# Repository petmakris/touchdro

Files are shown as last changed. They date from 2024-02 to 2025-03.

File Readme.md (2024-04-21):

# Parts

* ESP32 DEVKIT V1
    - https://www.aliexpress.us/item/2255800094862861.html

* Micro USB Connector Breakout 

  - https://www.aliexpress.com/item/1005006088838882.html

* ±5% 100V 100nF -40℃~+110℃ Metallized Polyester Plugin,P=5mm

    - [C3034534](https://www.lcsc.com/product-detail/Film-Capacitors_KNSCHA-MEB104J100V82CB0018_C3034534.html)

* 47uF 50V ±20% 180mA@100kHz Plugin,D6.3xL12mm 

    - [C2831773](https://www.lcsc.com/product-detail/Aluminum-Electrolytic-Capacitors-Leaded_KNSCHA-03EC0571_C2831773.html)

* Metal Film Resistors 4.7kΩ 250mW ±100ppm/℃ ±1%
 
    - [C119339](https://www.lcsc.com/product-detail/Through-Hole-Resistors_CCO-Chian-Chia-Elec-MF1-4W-4-7K-1-T_C119339.html)

* Metal Film Resistors 47kΩ 250mW ±50ppm/℃ ±1%

    - [C410613](https://www.lcsc.com/product-detail/Through-Hole-Resistors_TyoHM-RN-1-4W-47K-F-T-B-A1_C410613.html)

* SN74HC14N Schmitt Trigger 6 21ns@6V,50pF 2uA 2V~6V DIP-14 Inverters ROHS

    - [C2907](https://www.lcsc.com/product-detail/Inverters_Texas-Instruments-SN74HC14N_C2907.html)

# Micro USB Breakout

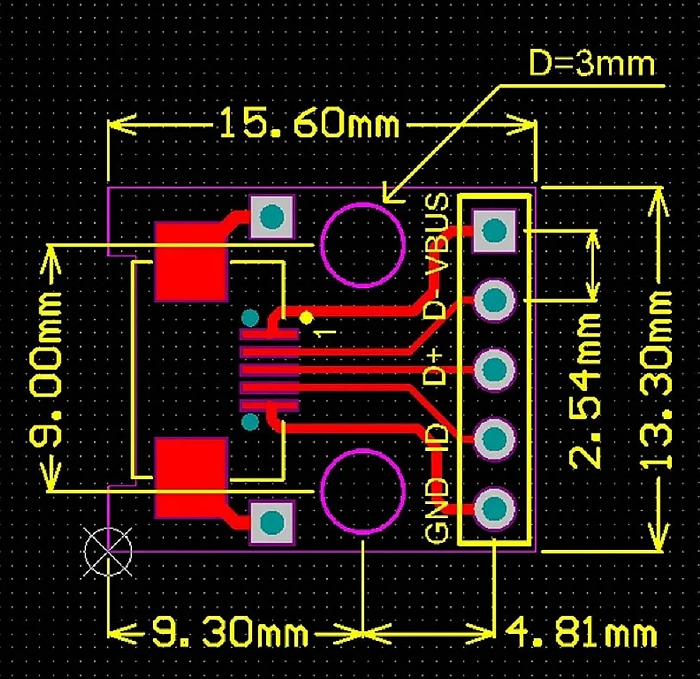
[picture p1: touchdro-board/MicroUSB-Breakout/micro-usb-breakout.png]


# ESP32 DevKit V1

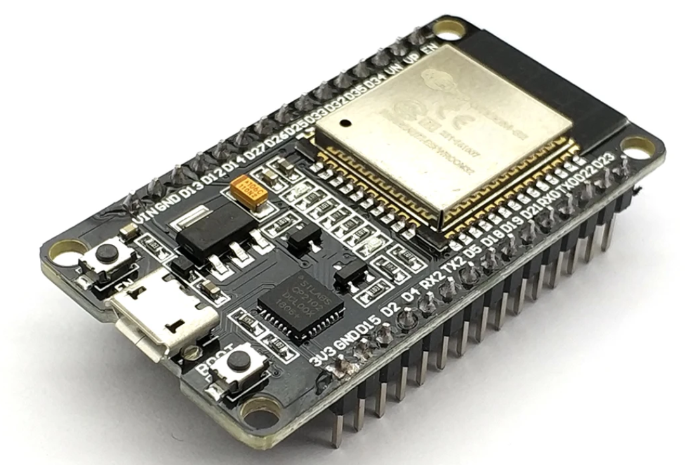
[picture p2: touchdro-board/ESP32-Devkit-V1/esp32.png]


# Firmware

```bash
esptool.py --chip esp32 --port COM5 --baud 460800 --before default_reset --after hard_reset write_flash --flash_mode dio --flash_size detect --flash_freq 40m 0x1000 bootloader.bin 0x8000 partition-table.bin 0x10000 touchdro-diy-universal-1.6.bin
```

It seems that for the esp32 to broadcast you need to keep the boot 
button pressed

# References

- https://www.touchdro.com/resources/adapters/diy/esp32-diy-dro.html
- https://gitlab.com/VictorLamoine/kicad

https://www.touchdro.com/resources/adapters/diy/esp32-diy-dro.html

# Ordering from JLCPCB

## Step 1

from within `PCB`: 

- Export Gerber files
- Export Drill Files

- Export Placement file
  - Separate files for front/back
  - Keep only top file
  - Remove components not to be mounted

## Step 2 

from within `Schematic`:

Create BOM compatible with JLCPCB the custom plugin from within our `kicad-libs` projecs:

KicadBOM

This plugin will include only the components with a `JLCPCB` attributes

# Production files

kicad_pos_to_cpl.py POSITION.POSITION-JLCPCB.csv overrides.json [overrides.json]

## Tune placement file

Example `overrides.json`:

```json
{
    "D3": 180,
    "Q1": 180,

    "U6": -90,
    "U8": -90
}
```

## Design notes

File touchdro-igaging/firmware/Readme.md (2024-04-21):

Boards:

# Glass and magnetic scales

Use STM32F103C8T6 
    - Support for TTL single ended or rs422 scales
    - Auto detection of pinout using analog switch matrix

# Capacitive scales

- iGaging DigiMag Remote DRO
- iGaging EZ-View DRO Plus
- AccuRemote DRO
- Shars Digital Machine Scale
- iGaging Absolute DRO Plus
...

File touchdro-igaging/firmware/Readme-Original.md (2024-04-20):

NOTE: This program supports pulse sensor to measure rpm and switch type touch probe.  
For quadrature encoder scales use LS7366R-based shield.

If at least one quadrature scale is used do not conect other devices to SPI dedicated pins
as LS7366R uses SPI for communication

Configuration parameters:

- `SCALE_<n>_ENABLED`

Defines if DRO functionality on axis <n> should be supported.
If supported DRO scale should be connected to I/O pin defined in constant "<n>DataPin" and
DRO data is sent to serial port with corresponding axis prefix (X, Y, Z or W)
Clock pin is common for all iGaging scales should be connected to I/O pin defined in constant "clockPin"
Possible values:
    0 = DRO functionality on axis <n> is not supported
    1 = DRO functionality on axis <n> is supported
Default value = 1

- `SCALE_<n>_TYPE`

Defines the type of scale used on axis <n>.
Two types of scales are supported: iGaging/AccuRemote Digital Scales and  quadrature encoder scales (common glass or magnetic)
Note: If at least on scale is type 1 do not connect any other devices to SPI pins as it will interfere with communication with LS7366R.
Possible values:
    0 = iGaging/AccuRemote Digital Scales with 21bit protocol
    1 = Quadrature Encoder scales through LS7366R-type shield (32-bit quadrature counter with serial interface).
Default value = 0

- `SCALE_CLK_PIN`

Defines the I/O pin where clock signal for all iGaging DRO scales is connected.  Used only if at least one scale is type 0.
Possible values:
    integer number between 2 and 13
Default value = 2

- `SCALE_<n>_PIN`

Defines the I/O pin where DRO data signal for selected scale is connected
Note: For quadrature scale this pin is connected to SPI SS pin in corresponding LS7366R.
Possible values:
    integer number between 2 and 13
Default values = 3, 4, 5, 6 (for corresponding axis X, Y, Z and W)

- `SCALE_<n>_AVERAGE_ENABLED`

Defines if DRO reading should be averaged using weighted average calculation with automating smoothing factor.
If average is enabled the reading is much more stable without "jumping" and "flickering" when the scale "can't decide" on the value.
Note: This value is not used when corresponding SCALE_<n>_ENABLED is 0
Possible values:
    0 = exact measured from the scale is sent
    1 = scale reading averaged using weighted average calculation with automatic smoothing factor
Default value = 1

- `AXIS_AVERAGE_COUNT`

Defines the number of last DRO readings that will be used to calculate weighted average for DRO.
For machines with power feed on any axis change this value to lower number i.e. 8 or 16.
Possible values:
    integer number between 4 and 32
Recommended values:
    16 for machines with power feed
    32 for all manual machines
Default value = 24

- `TACH_ENABLED`

Defines if tach sensor functionality should be supported.
If supported tach sensor should be connected to I/O pin defined in constant INPUT_TACH_PIN and
rpm value is sent to serial port with axis prefix "T"
Possible values:
    0 = tach sensor functionality is not supported
    1 = tach sensor functionality is supported
Default value = 1

- `INPUT_TACH_PIN`

Defines the I/O pin where tach sensor signal is connected
Possible values:
    integer number between 2 and 13
Default value = 7

- `TACH_PRESCALE`

Defines how many tach pulses per one revolution the sensor sends.
For example if tach sensor uses two magnets on the shaft the sensor will generate two pulses per revolution.
This can be used to get better resolution and faster response time for very low rpm
Note: This value is not used when TACH_RAW_DATA_FORMAT is enabled
Possible values:
    any integer number greater than 0
Default value = 1

- `TACH_AVERAGE_COUNT`
  
Defines the number of last tach readings that will be used to calculate average tach rpm.
If you want to send measured rpm instead of average rpm set this value to 1.
Note: This value is not used when TACH_RAW_DATA_FORMAT is enabled.
        It is recommended to set this value 2 times or more of TACH_PRESCALE value.
        For example: if TACH_PRESCALE = 4, set TACH_AVERAGE_COUNT = 8
Possible values:
    1 = exact measured tach reading is sent
    any integer number greater than 1 - average tach reading is sent
Default value = 6

- `TACH_ROUND`
    Defines how tach reading should be rounded. If rounding is enabled the reading can be rounded either by 1% of current rpm or to the fixed "round" number with predefined RPM thresholds ("smart rounding"). For example with 1% rounding if measured rpm is between 980rpm and  1020 rpm the display will show numbers rounded to 9 and 10 (i.e. 981, 990, 999, 1000, 1010, 1020 etc.). With "smart rounding" the measured rpm is rounded to the nearest 1, 2, 5, 10, 20, 50 and 100 depends on measured RPM (change at predefined thresholds). For example with "smart rounding" all measured rpm is between 500pm and  2000 rpm the display will show numbers rounded to the nearest 5 (i.e. 980, 985, 990, 995, 1000, 1005  etc.). Note: This value is not used when TACH_RAW_DATA_FORMAT is enabled Possible values: 0 = exact measured tach reading is sent 1 = tach reading is rounded to the nearest 1% of measured rpm (1% rounding) 2 = tach reading is rounded to the nearest "round" number with fixed thresholds ("smart rounding") Default value = 2

- `TACH_RAW_DATA_FORMAT`
    Defines the format of tach data sent to serial port.
    Note: when raw data format is used, then TACH_PRESCALE, TACH_AVERAGE_COUNT and TACH_ROUND are ignored
    Possible values:
        0 = tach data is sent in single value format: T<rpm>;
        1 = tach data is sent in raw (two values) format: T<total_time>/<number_of_pulses>;
    Default value = 0

- `MIN_RPM_DELAY`
    Defines the delay (in milliseconds) in showing 0 when rotation stops.  If rpm is so low and time between tach pulse
    changes longer than this value, value zero rpm ("T0;") will be sent to the serial port.
    Note: this number will determine the slowest rpm that can be measured.  In order to measure smaller rpm I suggest
            to use a sensor with more than one "ticks per revolution" (for example hall sensor with two or more magnets).
            The number of "ticks per revolution" should be set in tachometer setting in Android app.
    Possible values:
        any integer number greater than 0
    Default value = 1200 (the minimum rpm measured will be 50 rpm)

- `OUTPUT_TACH_LED_ENABLED`
    Defines if the tach LED feedback is supported.
    If supported the tach feedback LED should be connected to I/O pin defined in constant OUTPUT_TACH_LED_PIN below
    Possible values:
        0 = tach LED feedback functionality is not supported
        1 = tach LED feedback functionality is supported
    Default value = 1

- `OUTPUT_TACH_LED_PIN`
    Defines the I/O pin where the tach LED feedback is connected.
    Tach LED feedback indicates the status of INPUT_TACH_PIN for debugging purposes
    Possible values:
        integer number between 2 and 13
    Default value = 9

- `PROBE_ENABLED`
    Defines if touch probe sensor functionality should be supported.
    If supported touch probe should be connected to I/O pin defined in constant INPUT_PROBE_PIN.
    Possible values:
        1 = touch probe functionality is supported
        0 = touch probe functionality is not supported
    Default value = 1

- `INPUT_PROBE_PIN`
    Defines the I/O pin where touch probe signal is connected
    Possible values:
        integer number between 2 and 13
    Default value = 8

- `PROBE_INVERT`
    Defines if the touch probe input pin signal needs to be inverted (enter the signal level when touch probe is not touching).
    Possible values:
        0 = touch probe input pin signal is LOW (logical Zero) when touch probe is in "normal open" status (not touching)
        1 = touch probe input pin signal is HIGH (logical One) when touch probe is in "normal open" status (not touching)
    Default value = 0

- `OUTPUT_PROBE_LED_ENABLED`
    Defines if the touch probe LED feedback is supported.
    If supported the touch probe feedback LED should be connected to I/O pin defined in constant INPUT_PROBE_PIN below
    Possible values:
        1 = touch probe LED feedback functionality is supported
        0 = touch probe LED feedback functionality is not supported
    Default value = 1

- `OUTPUT_PROBE_LED_PIN`
    Defines the I/O pin where the touch probe LED feedback is connected.
    Touch probe LED feedback indicates the status of INPUT_PROBE_PIN for debugging purposes
    Possible values:
        integer number between 2 and 13
    Default value = 10

- `UART_BAUD_RATE`
    Defines the serial port baud rate.  Make sure it matches the Bluetooth module's baud rate.
    Recommended value:
        1200, 2400, 4800, 9600, 19200, 38400, 57600, 115200
    Default value = 9600

- `UPDATE_FREQUENCY`
    Defines the Frequency in Hz (number of timer per second) the scales are read and the data is sent to the application.
    Possible values:
        any integer number between 1 and 64
    Default value = 24

- `TACH_UPDATE_FREQUENCY`
    Defines the max Frequency in Hz (number of timer per second) the tach output is sent to the application.
    Note: This value must be a divider of UPDATE_FREQUENCY that would result zero reminder.
            For example for UPDATE_FREQUENCY = 24 valid TACH_UPDATE_FREQUENCY are: 1, 2, 3, 4, 6, 8, 12 and 24
    Possible values:
        any integer number between 1 and UPDATE_FREQUENCY
    Default value = 4

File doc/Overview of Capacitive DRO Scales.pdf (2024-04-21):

Home (https://www.touchdro.com/) > Resources (https://www.touchdro.com/resources/) > Capacitive DRO Scales

# Overview of Capacitive DRO Scales

Capacitive linear scales have been popular with budget-conscious home machinists for the better part of three decades. The main appeal of capacitive scales is their low cost that gives the hobbyists access to a functional digital readout for a fraction of the cost of an off-the-shelf DRO. On top of that, these scales can be easily cut to the needed size making them preferable for smaller machines. As is the case with all DRO scales, capacitive scales have their pros and cons, (https://www.touchdro.com/resources/scales/capacitive/pros-and-cons.html) so it's important to have at least a cursory understanding of the most important DRO scale characteristics. (https://www.touchdro.com/resources/scales/dro-scale-parameters.html)

There is a large number of capacitive scale models on the market offered by several manufacturers. While they might look similar on the outside, there are many important internal differences between capacitive DRO scales, (https://www.touchdro.com/resources/scales/capacitive/important-differences.html) including data format, communication protocol, and power supply voltage. The good news is that TouchDRO can interface with the vast majority of Chinese linear scales on the market, but different scales have different adapter hardware and firmware requirements. To make sure that you select the compatible combination of scales, TouchDRO adapter and firmware, please refer to the list below.

# Supported Scales

TouchDRO relies on custom adapter firmware to interface with various models of capacitive scales. At the time of this writing, most mainstream linear scales and a number of other specialty scales are supported. Each scale family had different interfacing hardware requirements and decoding firmware. The list below contains details about supported capacitive scale families, their important characteristics, and TouchDRO adapter compatibility.

Home (https://www.touchdro.com/) | Store (https://store.touchdro.com/) | Downloads (https://www.touchdro.com/downloads.html) | Documentation (https://www.touchdro.com/resources/)

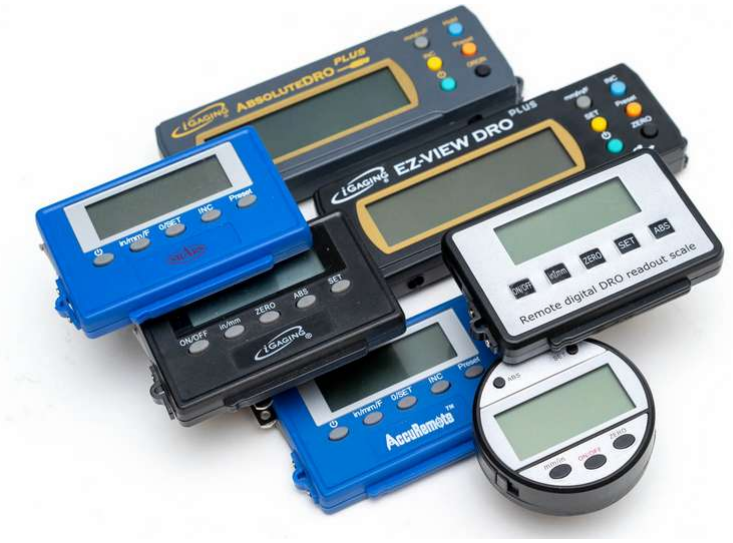
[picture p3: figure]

Please note that this list is not comprehensive. It's impossible to test and verify every scale model on the market; so, even if your scales are not listed, it might still work just fine with TouchDRO. You will need to do some research and testing on your own though.

## iGaging DigiMag Remote DRO

iGaging DigiMag was the first capacitive scale model with a display that can be mounted remotely. They use an extruded aluminum frame in conjunction with an injection-molded plastic transducer housing. The display is connected to the reading head using a USB cable that is glued to the transducer board and has a male plug on the display end. The scales are powered via two 3V cells connected in parallel.
Read More (https://www.touchdro.com/resources/scales/capacitive/igaging-21-bit.html)

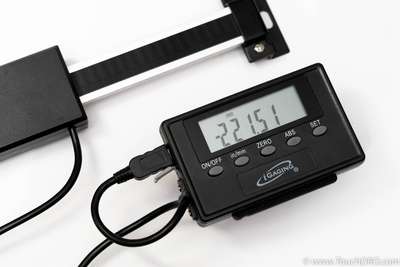
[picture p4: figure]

These scales were sold in some parts of the world under Shahe name or even without branding. They were identical to the iGaging version unlike the newer Shahe 4304-xxxA scales (shown further down) that use similar displays but are completely different and incompatible.

## iGaging EZ-View DRO Plus

iGaging EZ-View is the updated version of the classic iGaging DigiMag Remote DRO scales. The scales use an extruded aluminum frame with an injection-molded plastic reading head and a large stackable display. Ignoring the difference in the display, these scales are basically identical to their predecessor.

Read More (https://www.touchdro.com/resources/scales/capacitive/igaging-21-bit.html)

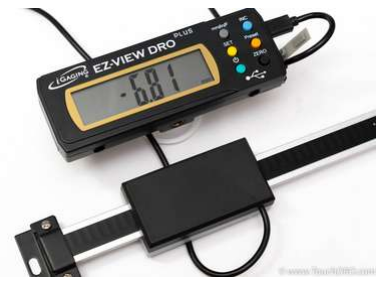
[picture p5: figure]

## AccuRemote DRO

AccuRemote DRO scales are rebranded and upgraded DigiMag scales. They electronically identical to the iGaging scales but use a precision ground stainless steel frame with machined stainless steel encoder housing along with blue plastic.
Read More (https://www.touchdro.com/resources/scales/capacitive/igaging-21-bit.html)

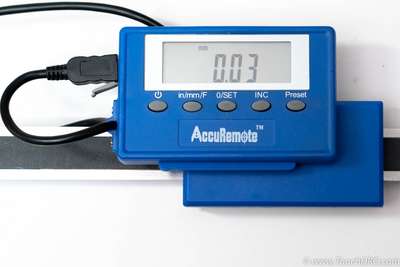
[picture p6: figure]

## Shars Digital Machine Scale

Shars Digital Machine Scales are another example of rebranded DigiMag scales. These scales come in two flavors: with extruded aluminum frame and plastic encoder housing similar to the iGaging DigiMag scales, and with stainless steel frame and encoder housing similar to the AccuRemote DRO scales.
Read More (https://www.touchdro.com/resources/scales/capacitive/igaging-21-bit.html)

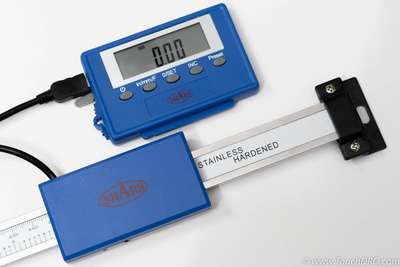
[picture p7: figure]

## iGaging Absolute DRO Plus

iGaging Absolute DRO Plus scales use a true absolute encoder and stainless steel frame/encoder housing along with the large stackable display. These scales are incompatible with other iGaging scales since they use a completely different data format and communication protocol.
Read More (https://www.touchdro.com/resources/scales/capacitive/igaging-absolute-dro.html)

There is an older version of Absolute DRO scales without the "Plus" designation

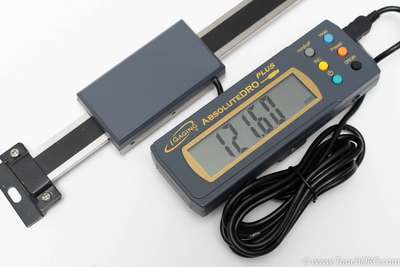
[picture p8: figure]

that uses a completely different data protocol and is incompatible with TouchDRO.

## Shahe Digital Liner DRO Scales with Round Display

The "Round Display" Liner DRO scales (model 5403-xxx) are manufactured by Sanhe Measuring Instrument Co., Ltd. and have been introduced to the market relatively recently. Just like iGaging DigiMag and EZ-View, Shahe scales use an extruded aluminum frame, plastic housing, and are powered by a 3V battery. Internally, they use a completely different encoder strip and send the data in BIN 6 format. Also, a notable fact is that these scales have the cable hard-wired into the display; on the other side, some samples come with a USB connector while others come hard-wired into the reading head as well.

Read More (https://www.touchdro.com/resources/scales/capacitive/shahe-dro-scales.html)

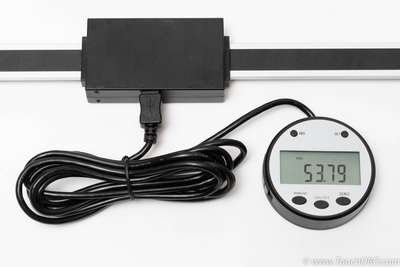
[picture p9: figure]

## Shahe Digital Linear DRO Scales with "Square" Display

The "Square Display" version of the scales (model 5403-xxxA) is similar to the "Round Display" model but uses a display that is similar to the iGaging DigiMag scales. Internally both Shahe models are identical. They rely on the same encoder stip and PCB and transmit the data in the same format but have some minor differences.
Read More (https://www.touchdro.com/resources/scales/capacitive/shahe-dro-scales.html)

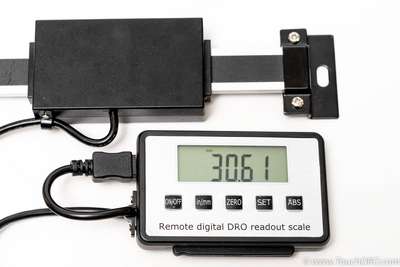
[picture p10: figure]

## Shahe Vertical Type Digital Linear Scale

These scales are based on the same encoder and use the same data format as the Shahe "Digital Linear DRO Scales" scales but have a few notable differences. They use a precision ground stainless frame with machined stainless steel housing, a display that is built into the reading head, and a USB data port. Even though these scales are powered by a 3V cell, the data stream is scaled down to 1.5V.
Read More (https://www.touchdro.com/resources/scales/capacitive/shahe-dro-scales.html)

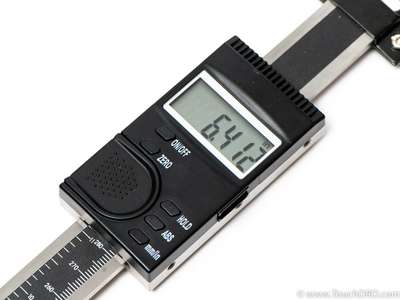
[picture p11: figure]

## Generic Chinese Linear Scales

This family includes many different scales from a number of manufacturers. These scales generally use stainless steel frame and encoder housing and are powered by a single 1.5V button cell battery. They use the traditional 4-pin caliper data port. Some of these scales might look like digital calipers with their jaws removed, but in most cases, they come with purpose-built displays, either vertical or horizontal.
Read More (https://www.touchdro.com/resources/scales/capacitive/generic-chinese-scales.html)

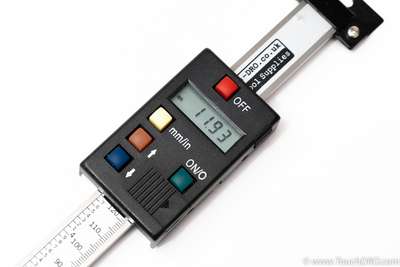
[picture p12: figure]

## Inexpensive Digital Calipers

Almost all inexpensive Chinese digital calipers on the market use the same 4-pin data port as the generic Chinese scales mentioned above and are powered from a single 1.5V button battery. Some manufacturers also sell linear scales that use the same frame and electronics but have the jaws remove and mounting holes added. Read More (https://www.touchdro.com/resources/scales/capacitive/chinese-digital-calipers.html)

Terms and Conditions (https://www.touchdro.com/terms-and-conditions.html) | Contact Us (https://www.touchdro.com/contact-us.html)
Privacy Policy (https://www.touchdro.com/app-privacy-policy.html)
Copyright 2012-2023 Yuriy's Toys, LLC.

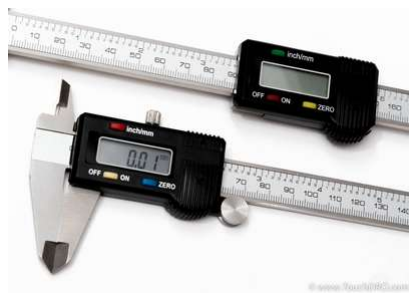
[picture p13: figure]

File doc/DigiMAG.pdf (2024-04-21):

## Connecting iGaging DigiMAG Scales to the Caliper2PC Interface – A step by step Guide

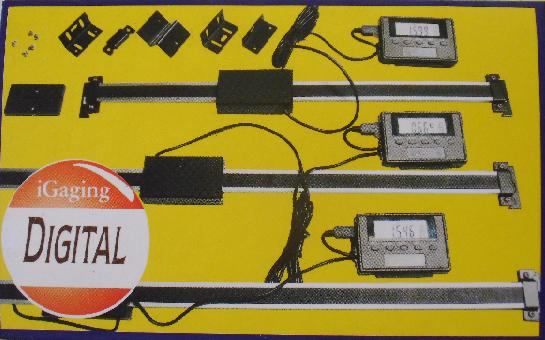
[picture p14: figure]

Copyright © Dipl.-Ing. Tomer Lanzman

www.caliper2pc.de

What is an iGaging DigiMAG Scale?

The iGaging DigiMAG are digital linear scales that are easily connectable to the

Caliper2PC interface.

They consist of two parts, the encoder and the readout unit. The encoder unit acts

as a slave, providing the data requested by the readout unit (the master). The data

is transmitted in 21 bit serial packages. Connecting the scale to the Caliper2PC

interface, the readout unit is not needed. To transfer the master tasks and to

translate the 21-bit-protocol, the 21BIT Adapter Kit is available. This adapter has to

be installed between the scale’s encoder and the Caliper2PC interface. The

following describes how to build and connect the 21BIT Adapter. The 21BIT

Adapter will fit into the scale’s encoder case, which will save a lot of wire mess.

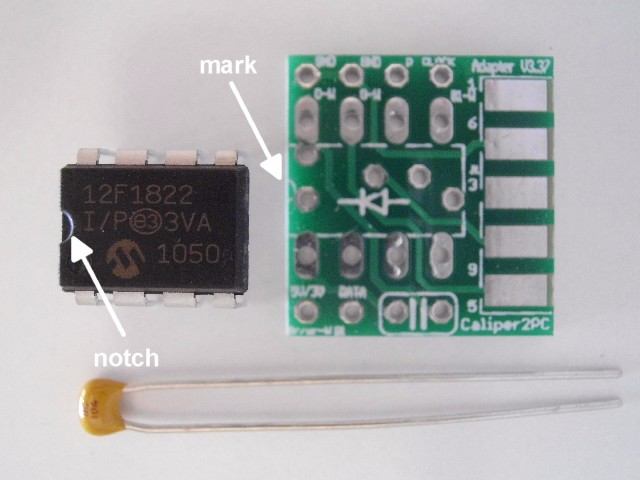
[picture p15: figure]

Copyright © Dipl.-Ing. Tomer Lanzman

BOM & Tools Needed

- 21BIT Adapter Kit (available at www.caliper2pc.de)
- RJ45 patch cable (available at any computer store)
- 1 inch of shrink tube (1.6mm – 3.2mm diameter) or insulating tape
- glue (ideally hot glue) or epoxy adhesive
- soldering iron and solder, as well as copper wire
- optional: 1 (or 2) micro switches
- wire cutter
- small round rasp or a Dremel

Building the 21BIT Adapter

The 21BIT Adapter Kit contains the adapter PCB, the converter IC and a 100nF

ceramic capacitor.

Double check that the IC is mounted in the right direction before the device is

soldered (notice the notch and the mark on the PCB).

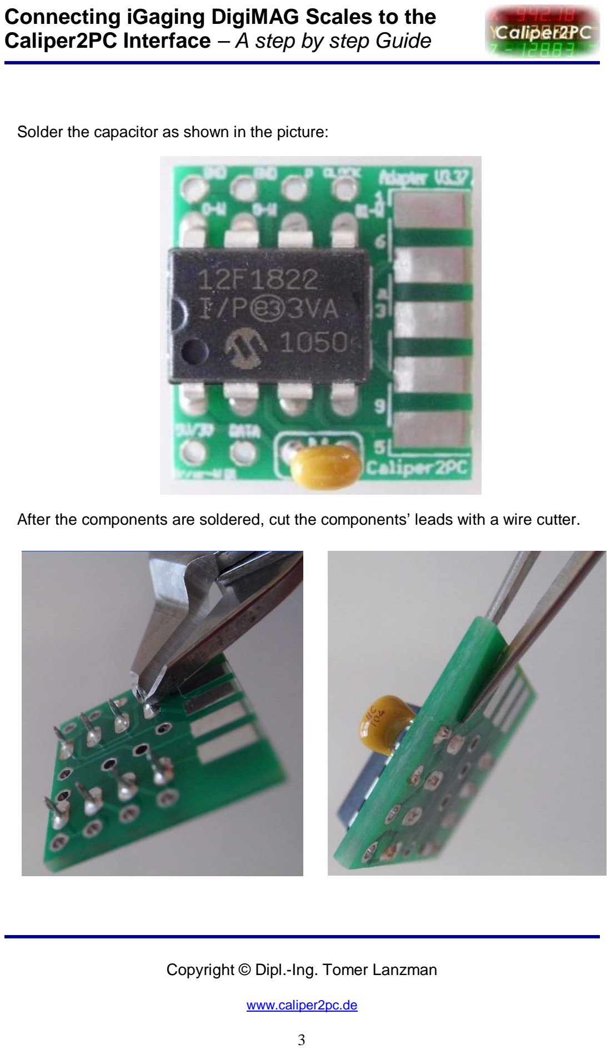
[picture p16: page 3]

Copyright © Dipl.-Ing. Tomer Lanzman

Solder the capacitor as shown in the picture:

After the components are soldered, cut the components’ leads with a wire cutter.

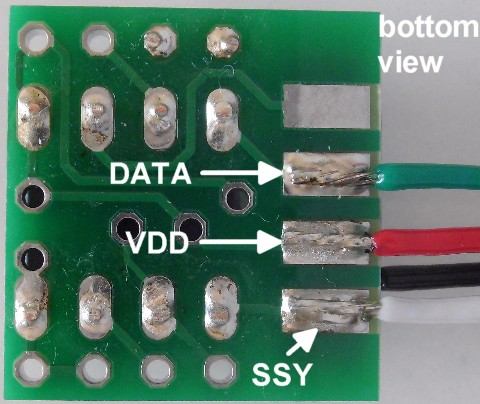
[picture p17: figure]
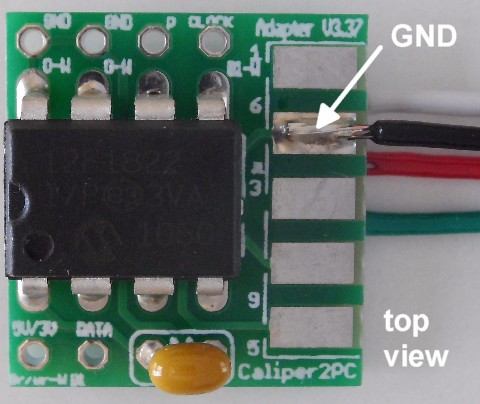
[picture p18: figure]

Copyright © Dipl.-Ing. Tomer Lanzman

Solder Cables to the 21BIT Adapter

The wires that will connect between the 21BIT adapter and the scale are soldered

first. The cable colors on the following pictures correspond to the 5 pin mini-USB

standard. The following color assignment is used:

- VDD | = red
- SSY | = white
- DATA = green
- GND = black

In the next step the RJ45 patch cable for connecting the 21BIT adapter to the

Caliper2PC interface will be prepared. Cut one of the connectors from the Patch

Cable with the desired cable length and then remove about 2 inches of the cable

sheath from the cut end. The following 4 wires of the patch cable are needed:

- Brown / White = +3V
- Orange / White = GND
- Blue / White | = CLOCK
- Blue | = DATA

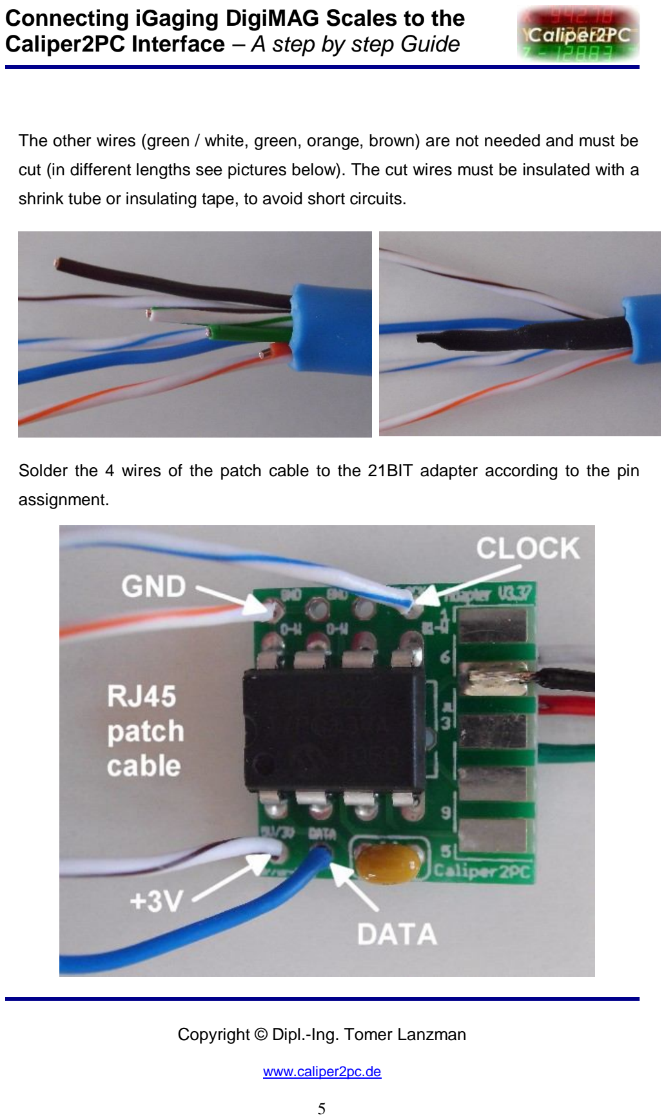
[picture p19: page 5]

Copyright © Dipl.-Ing. Tomer Lanzman

The other wires (green / white, green, orange, brown) are not needed and must be

cut (in different lengths see pictures below). The cut wires must be insulated with a

shrink tube or insulating tape, to avoid short circuits.

Solder the 4 wires of the patch cable to the 21BIT adapter according to the pin

assignment.

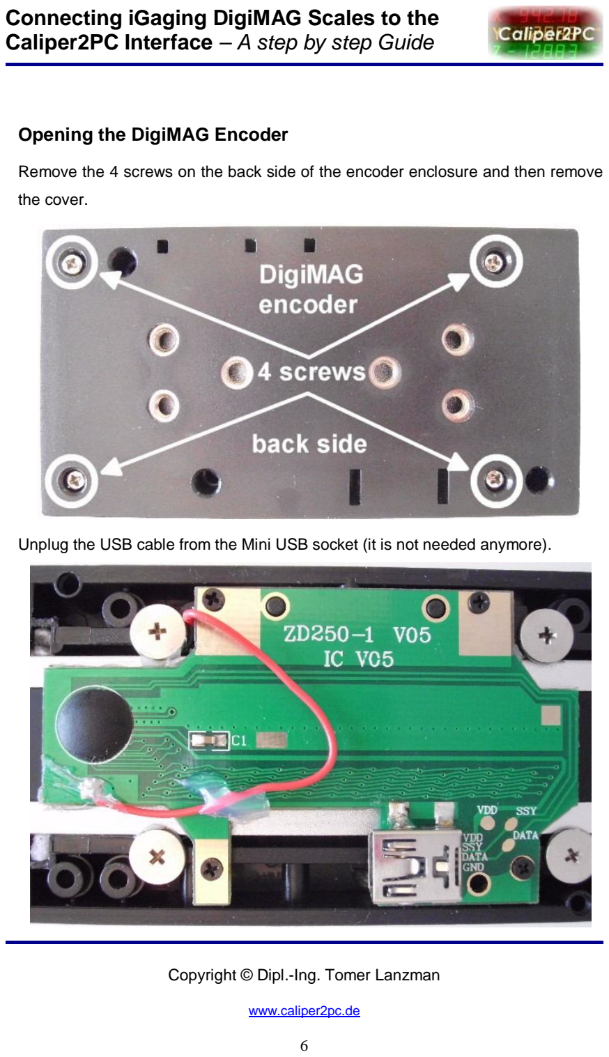
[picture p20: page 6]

Copyright © Dipl.-Ing. Tomer Lanzman

Opening the DigiMAG Encoder

Remove the 4 screws on the back side of the encoder enclosure and then remove

the cover.

Unplug the USB cable from the Mini USB socket (it is not needed anymore).

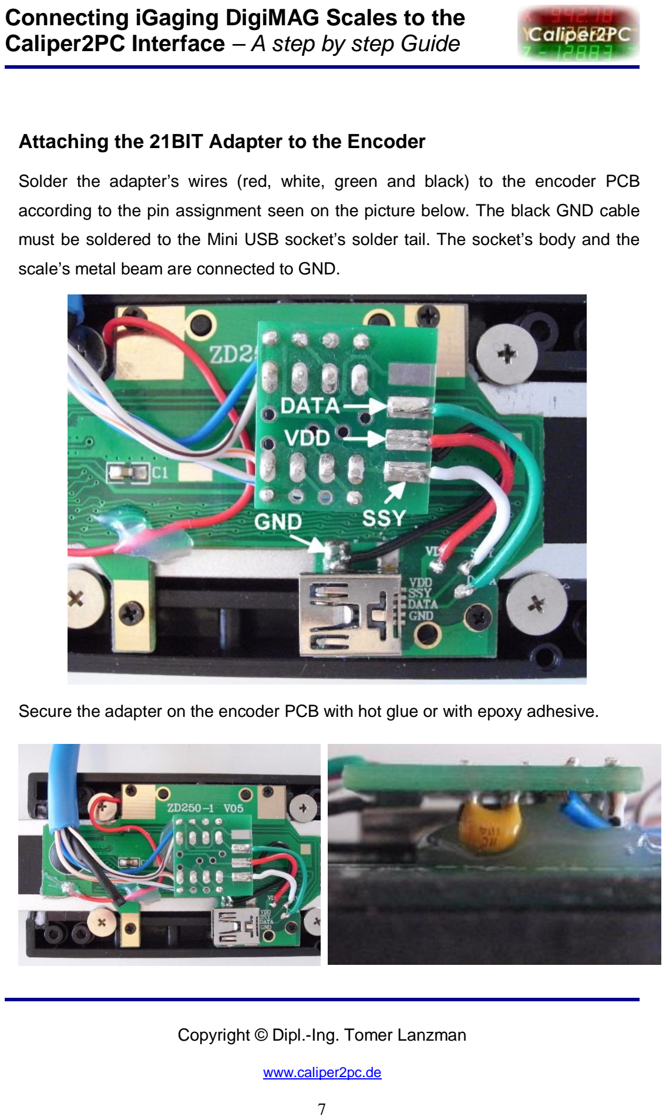
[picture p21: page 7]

Copyright © Dipl.-Ing. Tomer Lanzman

Attaching the 21BIT Adapter to the Encoder

Solder the adapter’s wires (red, white, green and black) to the encoder PCB

according to the pin assignment seen on the picture below. The black GND cable

must be soldered to the Mini USB socket’s solder tail. The socket’s body and the

scale’s metal beam are connected to GND.

Secure the adapter on the encoder PCB with hot glue or with epoxy adhesive.

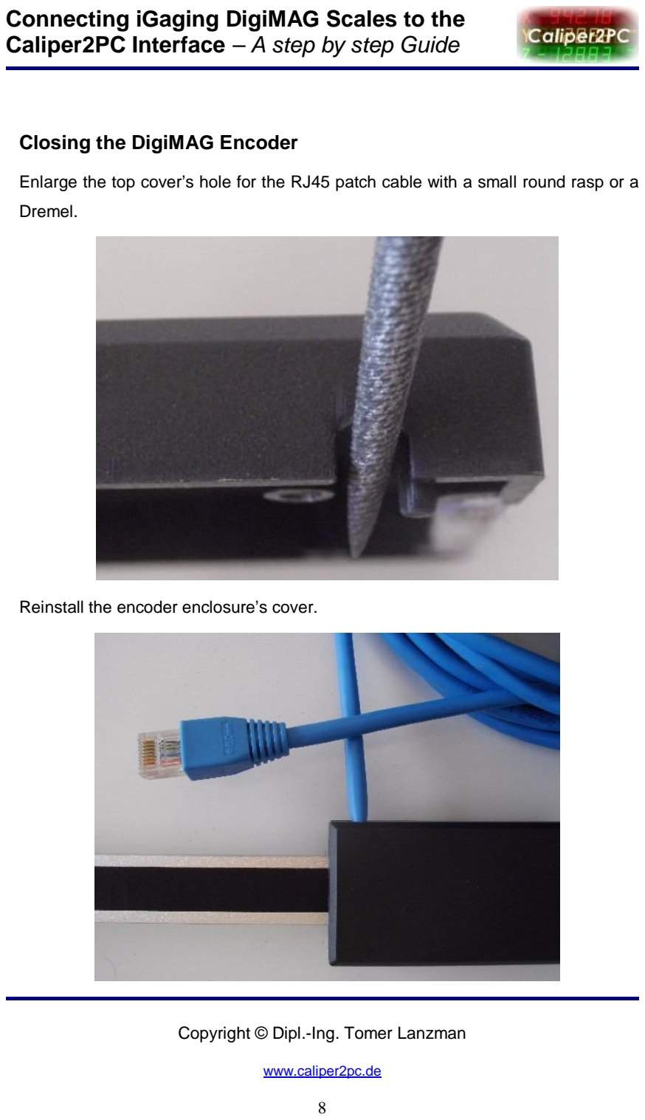
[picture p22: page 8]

Copyright © Dipl.-Ing. Tomer Lanzman

Closing the DigiMAG Encoder

Enlarge the top cover’s hole for the RJ45 patch cable with a small round rasp or a

Dremel.

Reinstall the encoder enclosure’s cover.

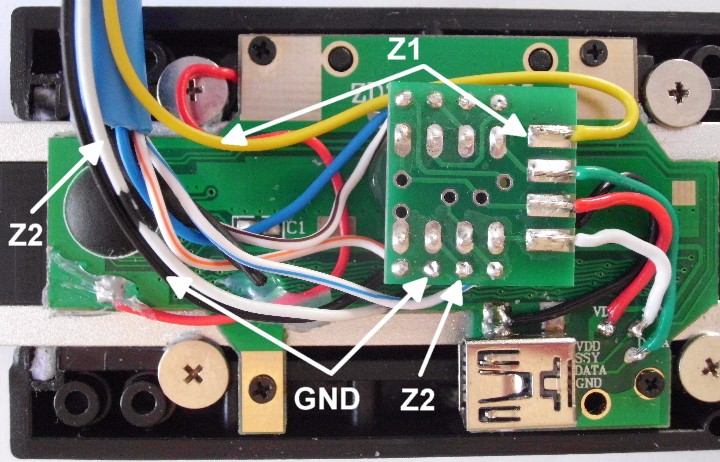
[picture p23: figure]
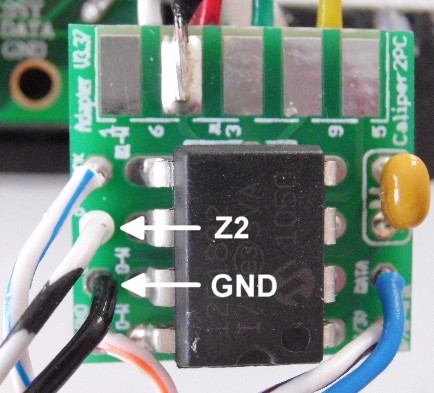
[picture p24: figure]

Copyright © Dipl.-Ing. Tomer Lanzman

Additional Features of the 21BIT Adapter

In addition to its functionality as a signal converter the 21BIT adapter possesses 2

input ports (Z1 and Z2). They can be used for connecting home switches, limit

switches, edge finder, or a tool length sensor. The input ports are active low and

can be triggered by switches when connecting to GND. The switch states are

recognized and processed in the Caliper2PC software. To connect switches to the

21BIT adapter 3 wires must be soldered according to the pictured pin assignments.

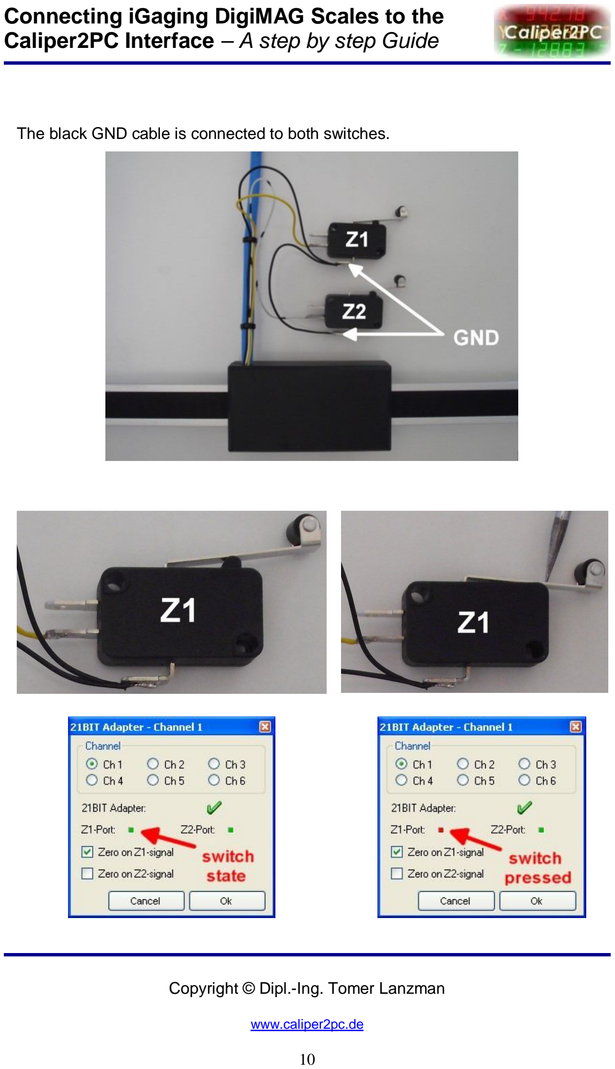
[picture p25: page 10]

Copyright © Dipl.-Ing. Tomer Lanzman

The black GND cable is connected to both switches.

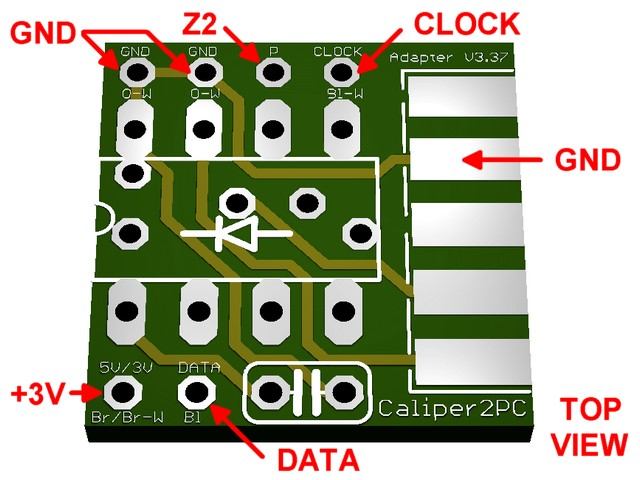
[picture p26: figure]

Copyright © Dipl.-Ing. Tomer Lanzman

The yellow cable is connected to the 21BIT adapter’s Z1 port. The pictures above

show the “open state” and the “closed state” of the Z1 switch. The switch state is

detected by the Caliper2PC software and can be used to automatically reset the

DRO. The path to the 21BIT adapter window in the Caliper2PC software is:

“Input” -> “Settings” -> “21BIT Encoder”

In the 21BIT adapter window the channel the 21BIT adapter is connected to must

be chosen.

Data Sheet 21BIT Adapter PCB


Copyright © Dipl.-Ing. Tomer Lanzman

Signals to Caliper2PC (RJ45 Patch Cable) | Signals to DigiMAG Encoder
- +3V • GND • CLOCK • DATA

(Brown / White) (Orange / White) (Blue / White) (Blue)
Pin 7 Pin 1 Pin 5 Pin 4 | • VDD
| • SSY
| • DATA (21BIT)
| • GND
| • Z1 (optional)
| • Z2 (optional)
PCB Measuring | Length | Width | Height
(Inch) | 0.630 | 0.602 | 0.049

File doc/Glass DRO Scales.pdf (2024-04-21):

Home (https://www.touchdro.com/) > Resources (https://www.touchdro.com/resources/) > Glass DRO Scales

# Glass DRO Scales


# Introduction

Glass DRO scales have been used in professional digital readouts for several decades. Until recently, Glass scales were prohibitively expensive and were relatively uncommon in hobby machine shops. Fortunately, Chinese glass DRO scales have significantly dropped in price putting them well within the reach of small shops and hobbyists.

At the moment, glass scales offer arguably the best balance of price/quality/performance. Due to the inherent stability of their glass encoder strip and the maturity of the manufacturing process, modern glass scales have excellent resolution and accuracy. Moreover, most modern glass scales have standardized on using 5V quadrature output, which makes scales from different brands easily interchangeable and easy to interface to TouchDRO system.

Glass scales are a form of a quadrature incremental optical encoder. They use a strip of a high-quality glass with evenly spaced microscopic marks etched into it and a photo-electronic reading head that moves along it. The marks are commonly spaced at 5 micron distance, but 1-micron versions are commonly available as well. The head contains a photo sensor that consists of photodiodes precisely spaced at a distance that is either 75% or

Home (https://www.touchdro.com/) | Store (https://store.touchdro.com/) | Downloads (https://www.touchdro.com/downloads.html) | Documentation (https://www.touchdro.com/resources/)

125% of the distance between marks. Scale's internal circuit conditions and amplifies the detected signal; so, the resulting output consists of two square waves that are 90 degrees out of phase. The DRO is able to detect the pulses from the scales and, by comparing the state of the two channels, interprets the direction of the movement.

Side note: incremental encoders don't inherently encode the position. Instead, they can precisely measure the movement of the machine's axis, and it's up to the DRO to increment or decrement the pulse count and infer the position from it. There are glass scales that can provide absolute position, but they are very rare, expensive, and generally are intended for specialized applications.

# Pros

## Excellent Accuracy

The encoder strip used inside the scales is made of high quality glass that has very low coefficient of thermal expansion; so, the scales have excellent thermal stability. Combined with the mature process of precision photo etching, glass scales are inherently very accurate.

## Superior Noise Resistance

Glass scales have the best electromagnetic interference resistance of all DRO scale types. This is due to the fact that they use photo sensors that are almost fully enclosed within metallic frames with only a narrow opening and the cable enclosed in a flexible metal shroud. In other words, the electronics and wiring are enclosed in a Faraday cage that shields them from any sort of electromagnetic, capacitive and inductive coupling. Combined with 5V signal level, this results in an excellent signal-to-noise ratio.

## Real-Time Signal

Glass scales use very simple signal processing and amplification circuits with no digital signal processing. Consequently, they provide a true real-time signal that results in no lag between scale movement and scale output.

# Cons

## Internal Backlash


Optical sensor carriage rides along the glass strip on a set of miniature bearings

In order to allow for flex and misalignment the coupling between the external reading head and the carriage that rides along the glass encoder, strip has to be somewhat flexible. Most common designs use a small piece of stiff spring wire to press the carriage against the strip. This arrangement has a small amount of inherent play that can result in backlash on the scale.

## Long-Term Durability

The marks on the encoder strip and the slits in the sensor are incredibly small. If dirt or coolant gets onto the encoder strip, the scale will not function properly. Furthermore, glass scales have more moving parts than any other type of scales, including several miniature ball bearings that ride along the glass strip. Over time, those bearings will wear and can exacerbate the backlash or simply fail and damage the encoder strip.

## Physical Size and Mounting Issues


Glass scales are much larger than either capacitive or magnetic DRO scales

Glass DRO scales are bulkier than most other scale types, come in a limited number of sizes, and can't be cut to fit machine dimension. On top of that, to avoid ingestion of dirt, they need to be mounted with the slit facing down or at least away from the cutter. As a result, they can take up a lot of space and, in some cases, restrict machine movement or limit functionality.

# TouchDROCompatibility

Virtually all Chinese glass DRO scales and majority of name-brand glass scales are compatible with TouchDRO. When purchasing a set of glass scleas for use with TouchDRO, it's important to obtain and study their pin mapping. Most reputable suppliers provide at least a basic spec sheet that includes a table or a diagram describing connector pin functions. If there are 0V, +5V, A, B, and R or Z lines, the scales are compatible. Optionally, there might be A', B', R'/Z' lines, which will be discussed later. On the other hand, if the scales has "Data", "Excitation" lines, uses negative supply voltage or supply voltage other than 5V, it is not compatible with TouchDRO.

# ImportantTechnicalParameters

In addition to the above, there are a few other important technical parameters that affect the price of the glass DRO scales.

## Differential vs. Single Ended Output

Glass DRO scales can output single ended TTL signal or differential signal using RS422 standard. In the former case, the scale uses single wire per channel. In the latter case, each channel uses two wires that carry complementary signals. In other words, when A is high, A' is low. Specialized RS422 decoder IC can then invert A' signal and sum it with the A signal. Since any noise present in the wire will also be inverted, it will be cancelled out, while the signal will be summed up. As a result, RS422 scales are even more resilient to noise and can be used with very long cable runs of tens or even hundreds of feet. TouchDRO adapter supports both types, but for most shops RS422 is not needed since the length of the cables is very short and is not worth the extra price.

## Resolution

Glass scales come in 1 micron and 5 micron resolution with the latter being significantly more expensive and somewhat less common. For use on a milling machine, a set of five micron scales will provide more than enough resolution. On a lathe, it's common to see a setup where a 5-micron scale is used for the Z axis and 1-micron scale is used for the cross slide to provide better resolution for diameter turning. A surface grinder will usually benefit from a set of 1-micron scales in order to reliably hold tolerances down to ten thousandths of an inch.

# QualityConsiderations

As is the case with many things made in China, the manufacturers build a product to customer's quality standards. Scales from the more well known Chinese brands such as Easson and Ditron are of excellent quality on par with more premium western brands. Unfortunately, many of the non-name and generic DRO scales are able to offer such a low price point by cutting some corners, using lesser quality components, and neglecting quality control.


Brand name Chinese scale (bottom) uses a much more sophisticated signal conditioning circuit

## Dirt and Coolant Protection

Glass scales are very sensitive to moisture and dirt that can enter their body. To protect against this, most glass scales have one or more layers of rubber seals running along the length of the slit. It's common for the slim models to have one set of seals, while regular sized models have two sets. Unfortunately, this is the area where some discount brands tend to cut cost, so it's important to ensure that the scale has the correct number of seals.

## Sensor Alignment

The marks on the encoder and the corresponding slits in the photodetector are incredibly small and for optimal performance need to be precisely aligned. If they are not perfectly parallel, the signal quality will be degraded and the scale will not perform optimally. Most scales have a way to adjust the alignment, usually via a small screw in the carriage. Since the alignment process takes extra time, this is the area where the manufacturers can cut corners.

## Non-Linear Error

Generally speaking, the encoder strips used in Chinese glass scales are very accurate and have little-to-none non linear error. Unfortunately, some online vendors intentionally use components that failed quality assurance to hit a low price point. As a result, it's possible to come across DRO scales with non-uniform ethiching or missing marks, which will introduce random errors throughout the length of the scale that are very difficult to detect without specialized calibration equipment.

Another component that can introduce position error are the miniature bearings that ride on the glass strip. Low quality bearings can introduce microscopic amounts of wobble into the carriage which can introduce cyclic error into the scale output.

## Assembly Issues

Final area that can affect performance and reliability of the scales is electronic and mechanical assembly. In most cases, the cables are soldered manually to the PCB inside the scales and to the connector pins. Cold solder joints or frayed wires can create intermittent issues during operation that can wreak havoc with the DRO. Furthermore, since the carriage is subject to constraint vibration, the screws can come loose if no thread locking compound is used.

# Bottom Line

Glass DRO scales offer a good balance of price, quality and performance and are in almost every way superior to the capacitive scales. They do have a few drawbacks such as sensitivity to dirt and moisture, internal backlash, and potential size issues. Despite those issues, glass scales completely dominate the DRO market thanks to their inherent stability, excellent accuracy and outstanding noise resistance.

Terms and Conditions (https://www.touchdro.com/terms-and-conditions.html) | Contact Us (https://www.touchdro.com/contact-us.html)
Privacy Policy (https://www.touchdro.com/app-privacy-policy.html) Copyright 2012-2023 Yuriy's Toys, (https://www.touchdro.com/app-privacy-policy.html) LLC.

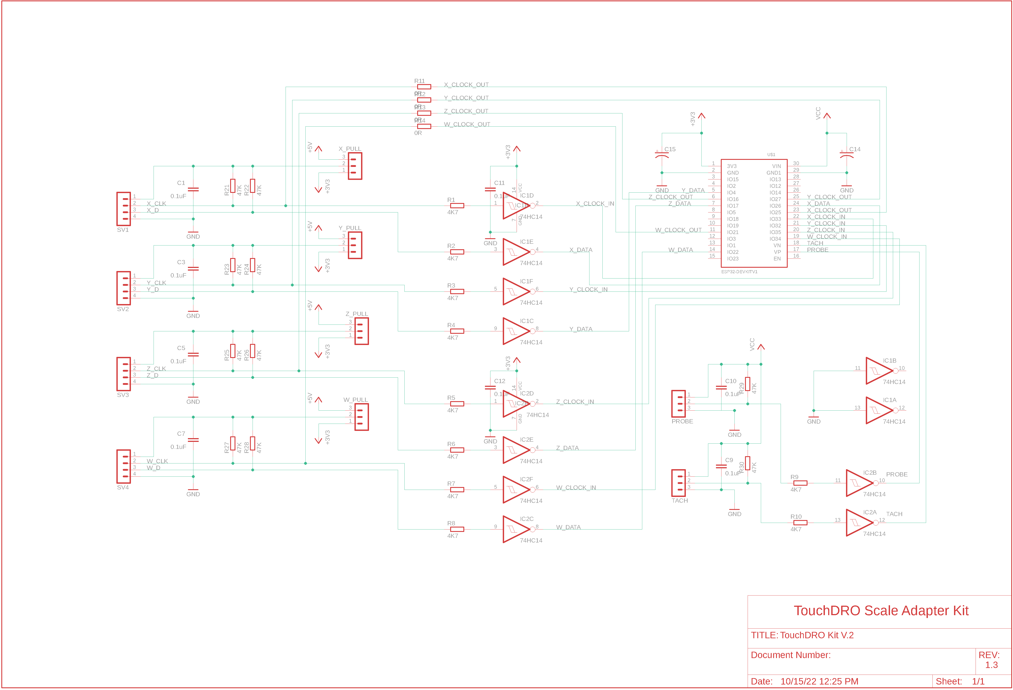
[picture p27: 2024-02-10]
esp32/touchdro-kit-v2-schematic.png

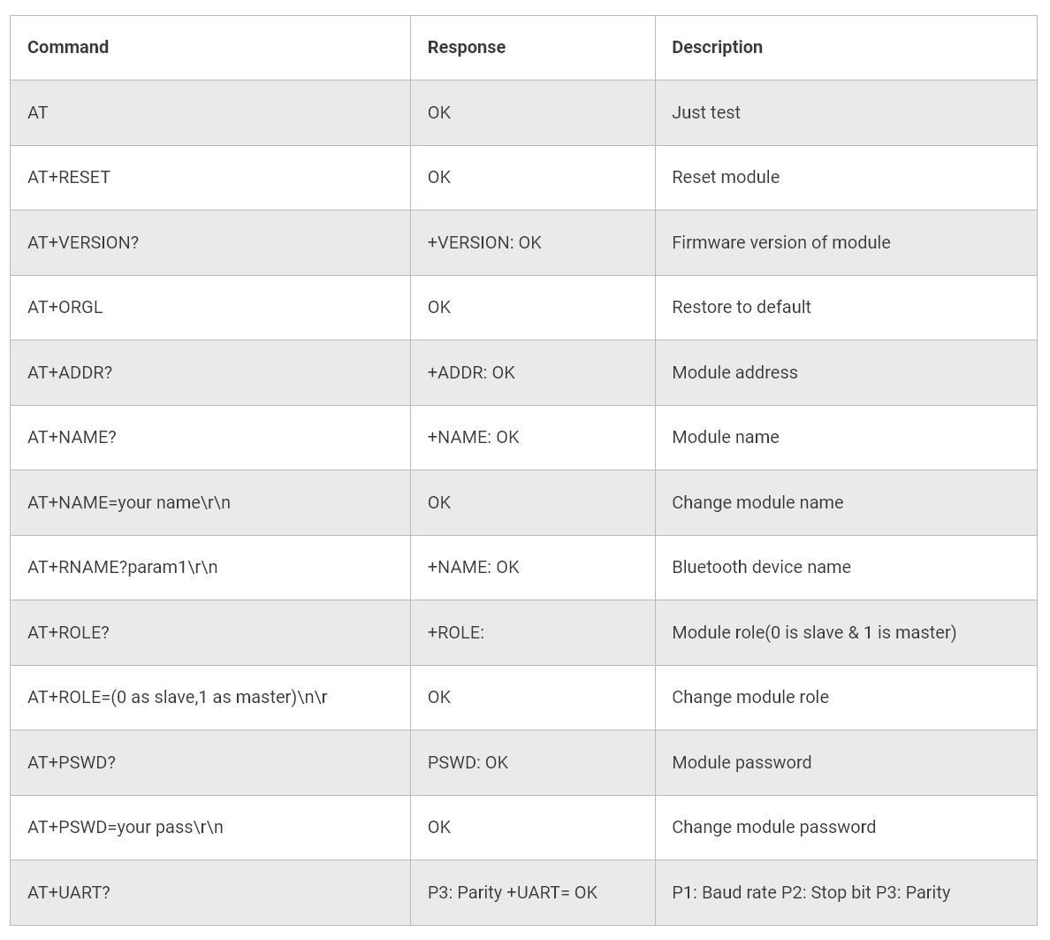
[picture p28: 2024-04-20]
touchdro-igaging/firmware/atcommands.png

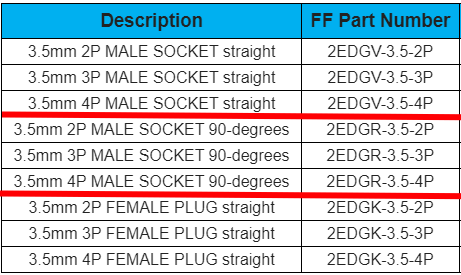
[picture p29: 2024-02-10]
esp32/touchdro-board/2EDGK/index.png

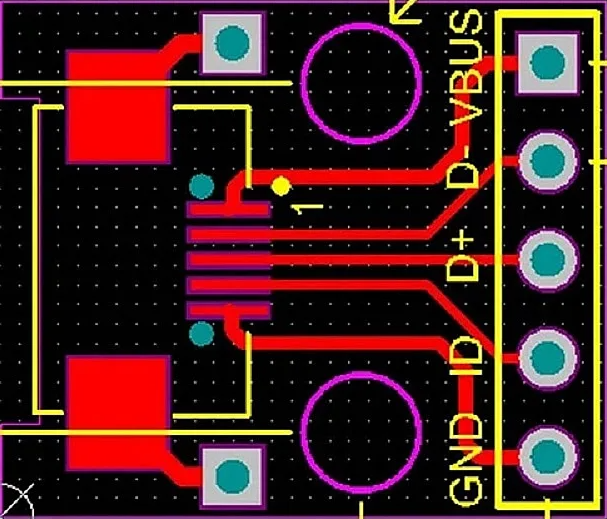
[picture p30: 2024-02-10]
esp32/touchdro-board/MicroUSB-Breakout/Outline.png

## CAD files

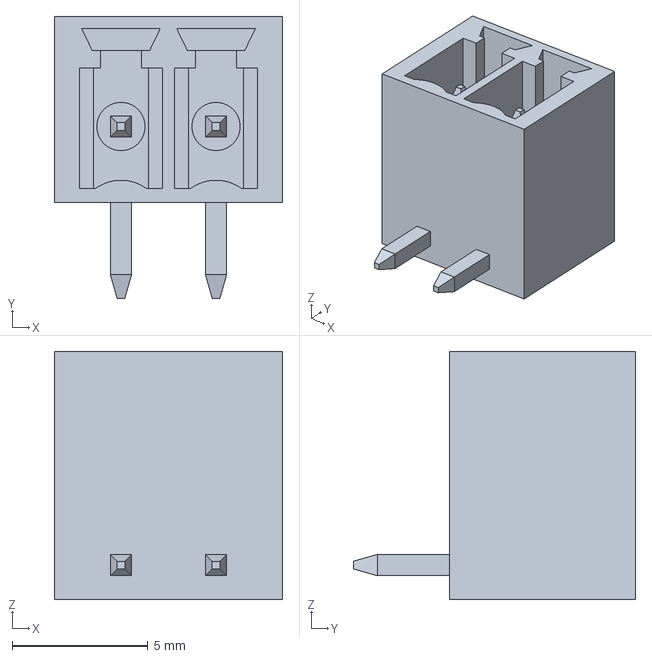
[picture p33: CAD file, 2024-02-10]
esp32/touchdro-board/2EDGK/modex-3d-models/molex-originals/right-39502-1502.stp
8.41 x 10.4 x 9.14 mm

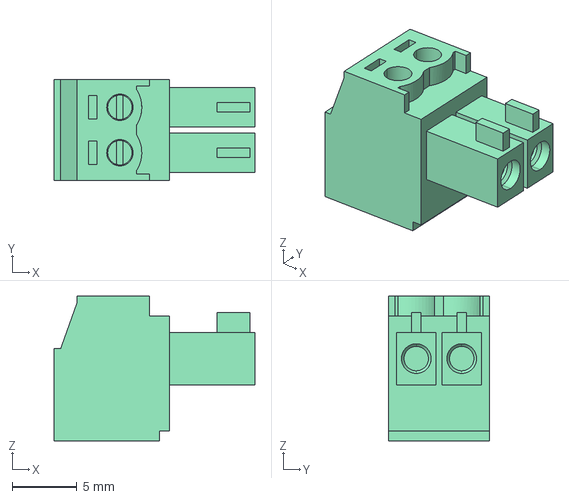
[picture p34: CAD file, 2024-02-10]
esp32/touchdro-board/2EDGK/modex-3d-models/plug/plug-39500-002.stp
15.5 x 7.80 x 11.2 mm

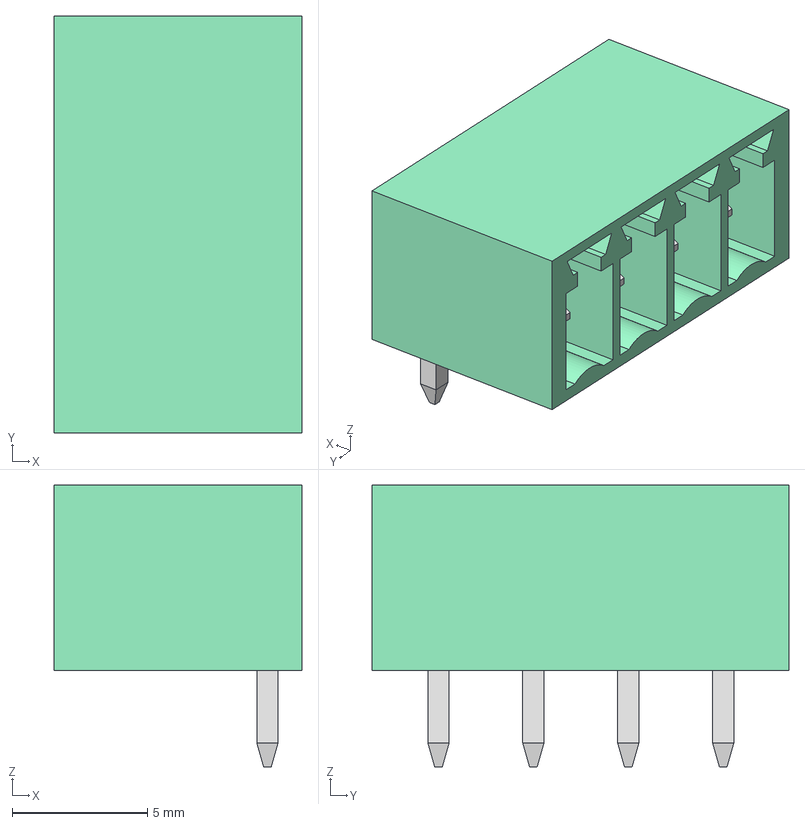
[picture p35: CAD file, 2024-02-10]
esp32/touchdro-board/2EDGK/modex-3d-models/right/right-39502-1504.stp
9.14 x 15.4 x 10.4 mm

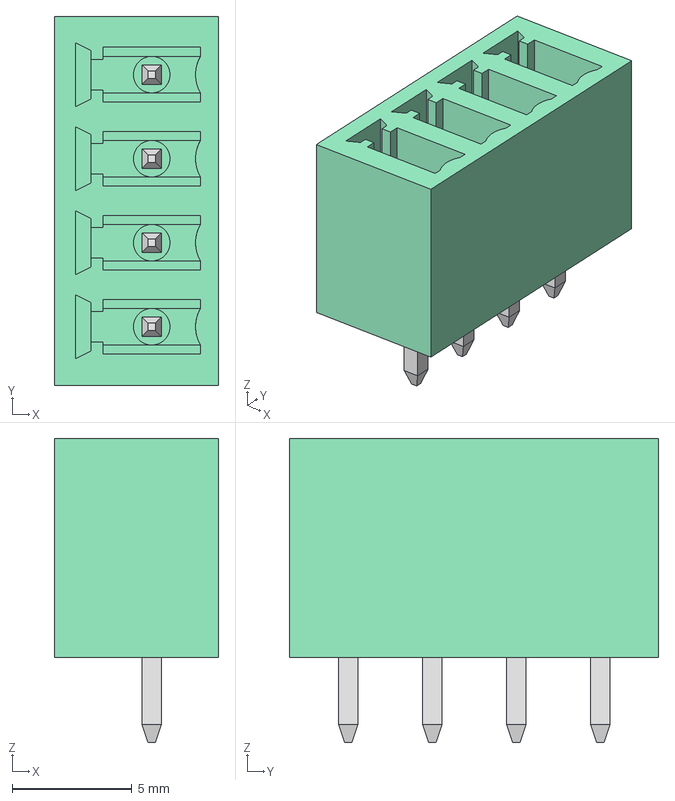
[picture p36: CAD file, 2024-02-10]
esp32/touchdro-board/2EDGK/modex-3d-models/vertical/vertical-395011-004.stp
6.86 x 15.4 x 12.7 mm

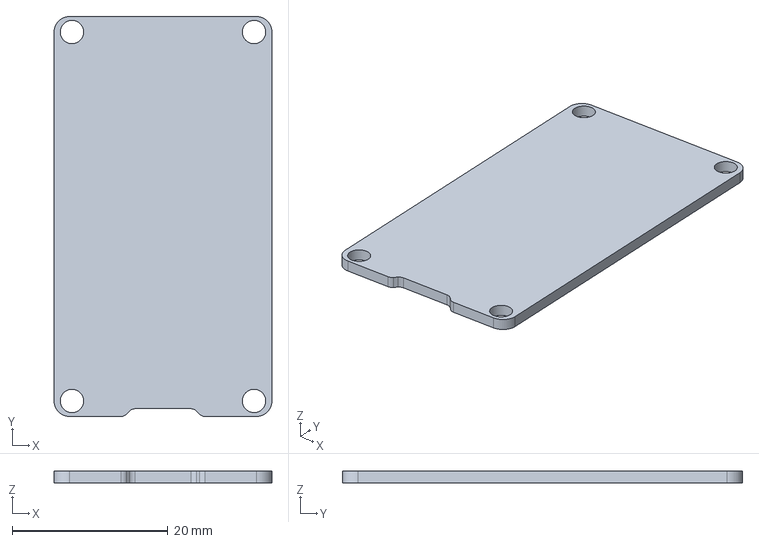
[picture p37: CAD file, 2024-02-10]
esp32/touchdro-board/ESP32-Devkit-V1/esp32_devkit_v1_doit.step
28.0 x 51.4 x 1.50 mm

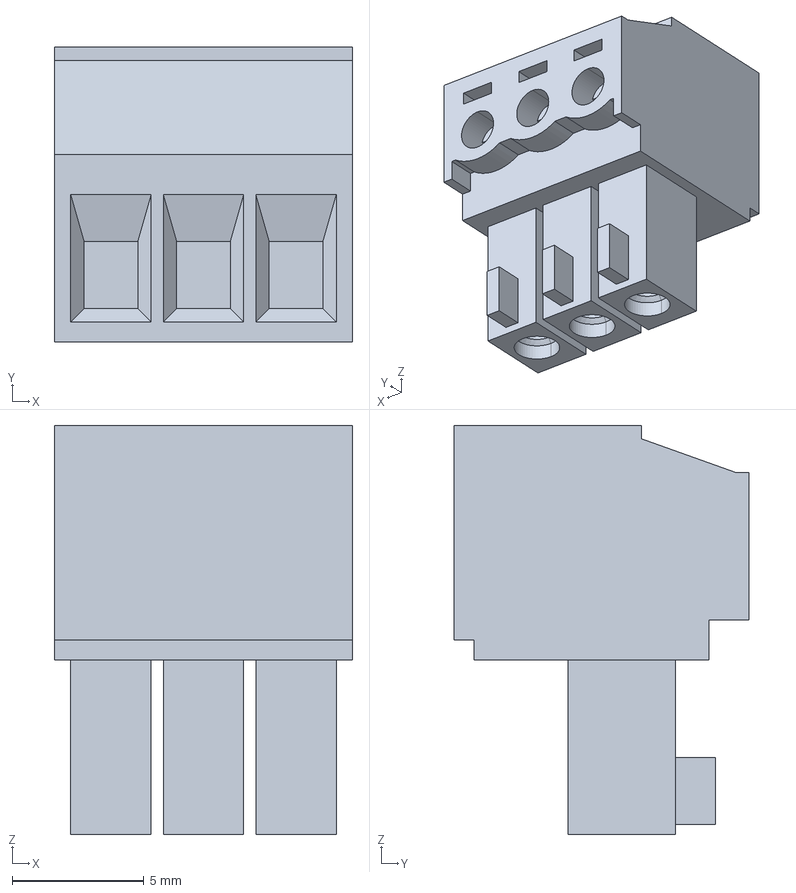
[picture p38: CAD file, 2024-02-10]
esp32/touchdro-board/2EDGK/modex-3d-models/molex-originals/plug-39500-003.stp
11.3 x 11.2 x 15.5 mm

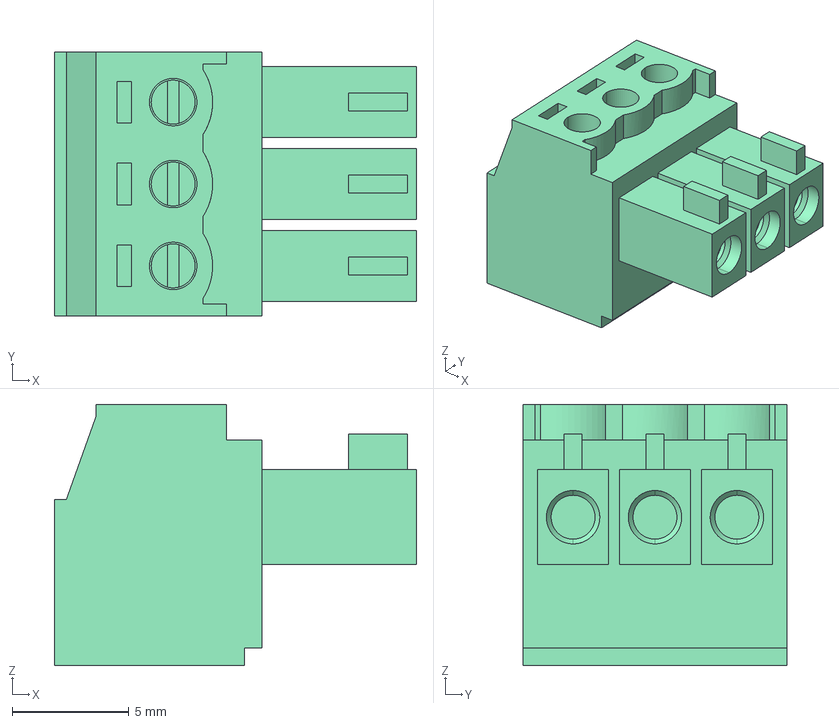
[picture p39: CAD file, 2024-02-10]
esp32/touchdro-board/2EDGK/modex-3d-models/plug/plug-39500-003.stp
15.5 x 11.3 x 11.2 mm

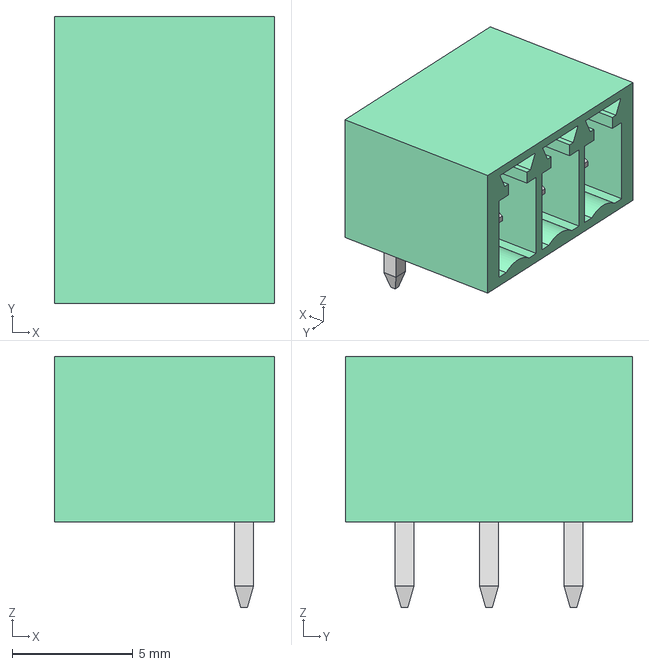
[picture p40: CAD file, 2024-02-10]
esp32/touchdro-board/2EDGK/modex-3d-models/right/right-39502-1503.stp
9.14 x 11.9 x 10.4 mm

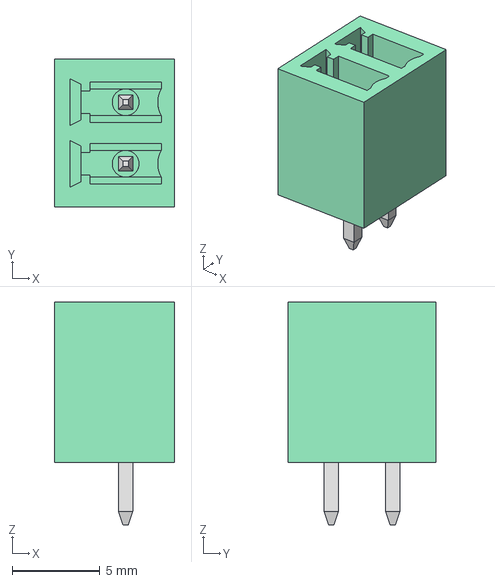
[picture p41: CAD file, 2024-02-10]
esp32/touchdro-board/2EDGK/modex-3d-models/vertical/vertical-395011-002.stp
6.86 x 8.41 x 12.7 mm

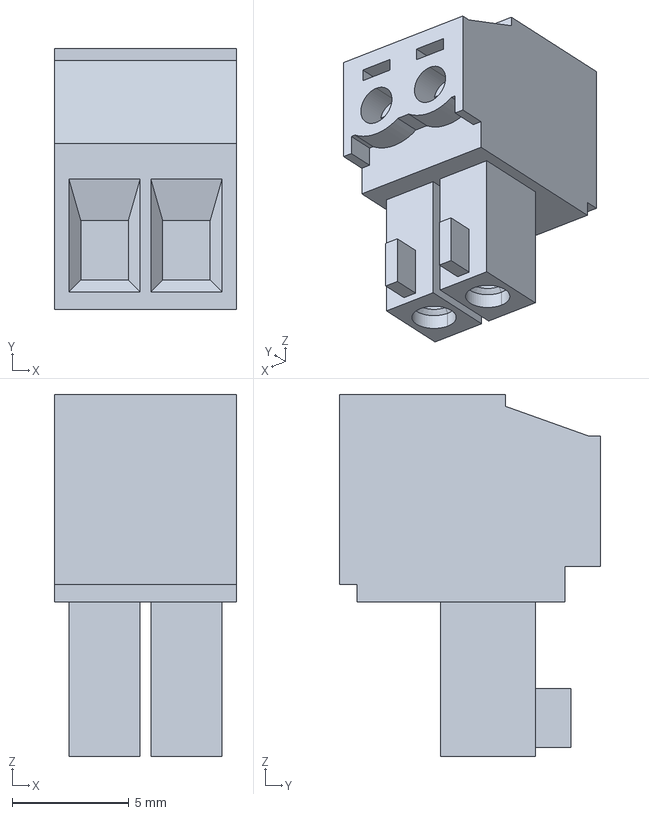
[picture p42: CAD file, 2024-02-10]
esp32/touchdro-board/2EDGK/modex-3d-models/molex-originals/plug-39500-002.stp
7.80 x 11.2 x 15.5 mm

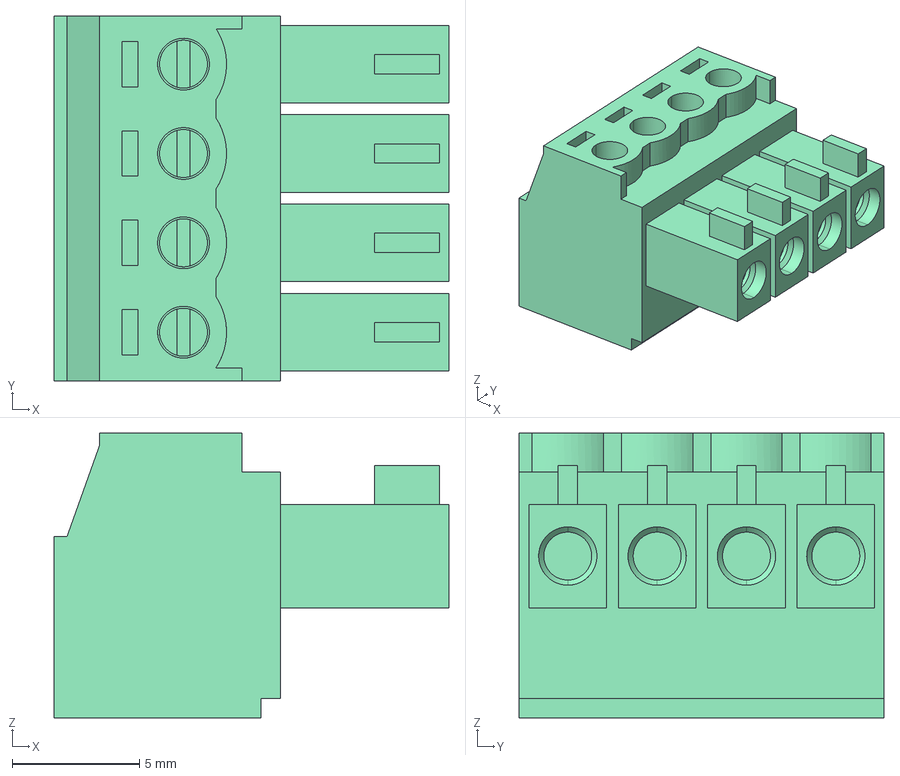
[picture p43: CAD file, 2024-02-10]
esp32/touchdro-board/2EDGK/modex-3d-models/plug/plug-39500-004.stp
15.5 x 14.3 x 11.2 mm

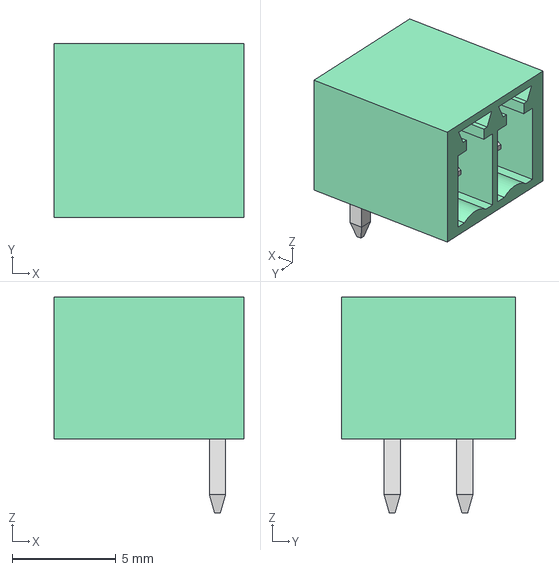
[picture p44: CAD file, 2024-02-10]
esp32/touchdro-board/2EDGK/modex-3d-models/right/right-39502-1502.stp
9.14 x 8.41 x 10.4 mm

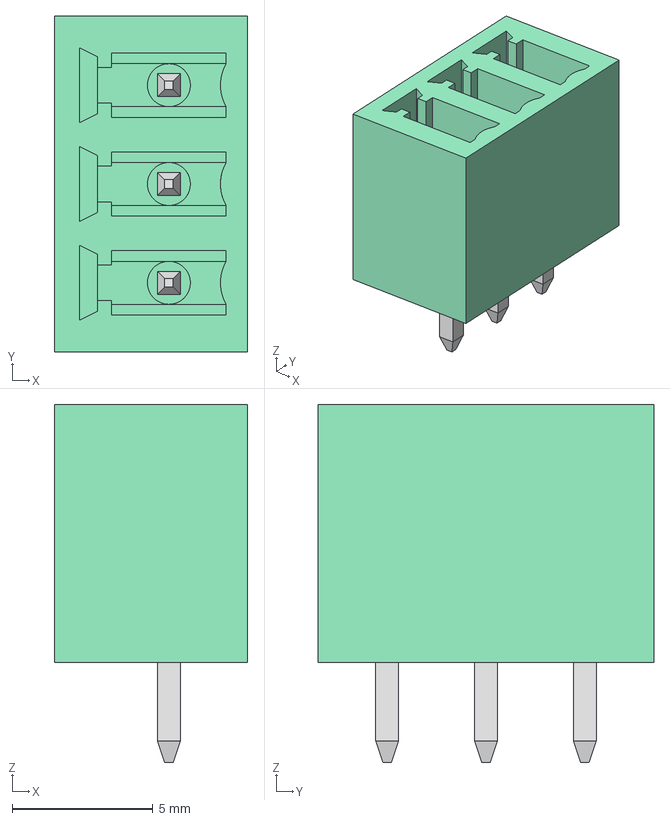
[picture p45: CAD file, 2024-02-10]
esp32/touchdro-board/2EDGK/modex-3d-models/vertical/vertical-395011-003.stp
6.86 x 11.9 x 12.7 mm

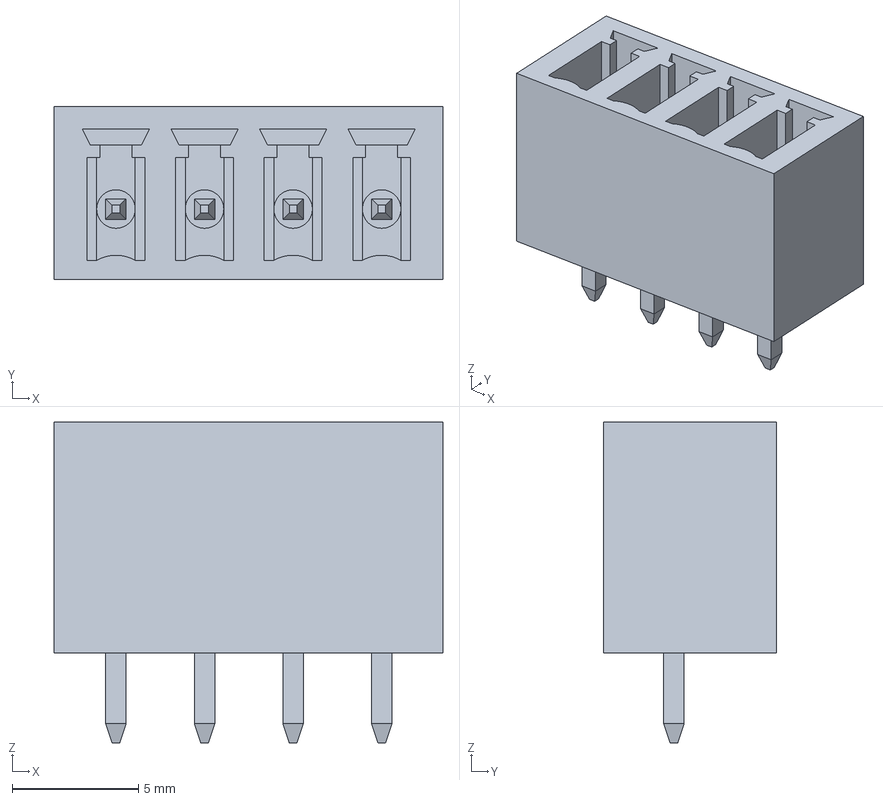
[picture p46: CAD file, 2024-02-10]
esp32/touchdro-board/2EDGK/modex-3d-models/molex-originals/vertical-395011-004.stp
15.4 x 6.86 x 12.7 mm

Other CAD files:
touchdro-igaging/design/enclosures/Z19.dwg
touchdro-igaging/design/enclosures/Z122.dwg
touchdro-igaging/design/enclosures/Z67.dwg
touchdro-igaging/design/enclosures/Z6.dwg
esp32/touchdro-board/2EDGK/modex-3d-models/molex-originals/plug-39500-004.stp
esp32/touchdro-board/2EDGK/modex-3d-models/molex-originals/right-39502-1503.stp
esp32/touchdro-board/2EDGK/modex-3d-models/molex-originals/right-39502-1504.stp
esp32/touchdro-board/2EDGK/modex-3d-models/molex-originals/vertical-395021-002.stp
esp32/touchdro-board/2EDGK/modex-3d-models/molex-originals/vertical-395021-003.stp
esp32/touchdro-board/2EDGK/modex-3d-models/plug/plug-39500-002.3dm
esp32/touchdro-board/2EDGK/modex-3d-models/plug/plug-39500-003.3dm
esp32/touchdro-board/2EDGK/modex-3d-models/plug/plug-39500-004.3dm
esp32/touchdro-board/2EDGK/modex-3d-models/right/right-39502-1502.3dm
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

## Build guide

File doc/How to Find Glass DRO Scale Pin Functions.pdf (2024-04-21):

Home (https://www.touchdro.com/) > Resources (https://www.touchdro.com/resources/) > Glass DRO Scale Pinout

# How to Find Glass DRO Scale Pin Functions

The prices of generic Chinese Glass DRO scales (https://www.touchdro.com/resources/scales/glass/overview.html) have come down over the last few years, putting them well within the reach of even the most budget-conscious machine shops. With careful shopping, a set of three scales for a mid-sized milling machine can be found for around $250 (USD). Even the most inexpensive Chinese glass DRO scales offer excellent quality, accuracy and reliability, making them a perfect choice for a DIY DRO setup. Unfortunately, as is often the case with goods purchased from China, product documentation and after-sales support is poor or non-existent. This can be especially problematic when the scales are purchased for use with TouchDRO setup instead of in a bundle with the manufacturer's DRO display unit.

Virtually all modern Chinese DRO scales use the same 5V supply voltage, output format and 9-pin D-Sub (AKA DB9) male connector, but the pinout is not standardized. On one hand, this means that for all intents and purposes these scales are interchangeable. On the other hand, if you ever need to connect a scale to a display unit from a different supplier, you will need to figure out what the pinout of the new scale is and move some lines around. Unfortunately, quite often the sellers are unwilling or unable to provide accurate documentation for their scales. Luckily, reverse-engineering the pinout of Glass DRO scales is pretty easy since they all use similar circuits with only minor variations.

Home (https://www.touchdro.com/) | Store (https://store.touchdro.com/) | Downloads (https://www.touchdro.com/downloads.html) | Documentation (https://www.touchdro.com/resources/)

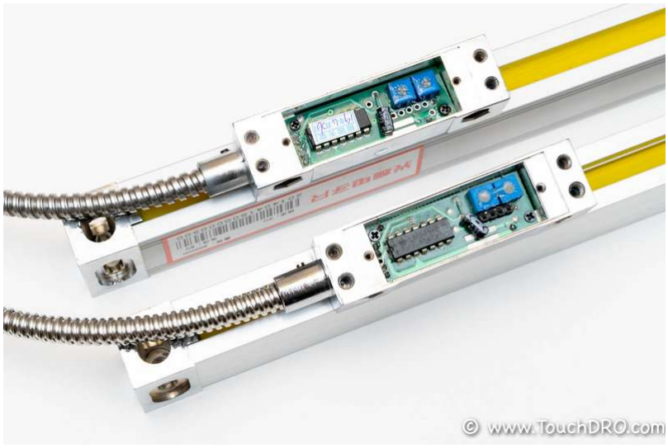
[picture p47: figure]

As is often the case with goods manufactured in China, it's hard to make any sense of brands and models because in most cases, the same products are sold under a number of different brands. In addition to the better-known brands such as Ditron, Easson, and Sino, there is a bewildering number of scales sold under names like Jino, Jink, Chino, etc. At a given price point, the scales look close to identical internally regardless of the brand, so it's likely that they are manufactured by a small handful of manufacturers and are re-branded for different distributors. For instance, the scales above are branded differently and were purchased more than two years apart from different sellers, yet the internal components look almost identical.

# What NottoDo

When you receive your DRO scales, you might be tempted to plug them in and see the numbers change on the screen. This is not a good idea. Unless you are sure that the wiring scheme is compatible, there is a chance that you will permanently damage the scales. The circuit in some of the cheaper scales is pretty basic and lacks any sort of reverse voltage protection or current limiting. If you get unlucky and the power pins are reversed, you can accidentally let out the "magic smoke".

Second, as mentioned earlier, brands are mostly meaningless when it comes to Chinese DRO glass scales. Many Chinese distributors buy batches of scales from the lowest bidder and simply stick their own logo on them. Once the batch is sold, they might get the next one from a completely different supplier. Consequently, you might find a wiring diagram for the scales of the same brand that is completely different from yours.

Finally, there is no standard color-coding. While you might be tempted to think that Red is +5V and Balck is 0V, this is very often not the case, and the color-coding is completely random. For instance, the scales pictured above had almost identical internal electronics but the wiring was different: one used Red, White, Yellow and Black wires for +5V, 0V, A and B respectively; the other used Red, Black, Blue, Green, Yellow for +5V, 0V, A, B, and R.

# ABit ofTheory

Most generic DRO scales on the market are simple linear optical encoders that output a 5V quadrature signal. The output consists of two square waves that are offset by 90 degrees. As the scale moves forward or back, the offset is either positive or negative, which allows the DRO to determine the direction of the travel and either increment or decrement the counter.

Customarily, these two output lines are labeled "A" and "B". In addition, some scales might have a "reference" output labeled "Z" or "R" that has a longer cycle and can be used for a basic error correction. Scales that have just A, B, and Z/R outputs are called "Single Ended". Often in the documentation for such scales, you might see the term "TTL". Although it's not strictly correct, this usually implies that the scales have 5V single-ended output.

For shorter cable runs, a single-ended signal is very reliable, but as the cable length increases, the signal integrity slowly degrades. Therefore, some of the more expensive Chinese DRO glass scales use a differential signal to negate the effect of line noise. For each of the signal lines (A, B, and R/Z) they include a line that sends an inverted signal. For instance, when A is high, A' is low, and vice versa. The DRO inverts A' and adds it to A; since the noise is also inverted, the spike is canceled out. Scales that offer differential output often include terms like "RS422" or "TIA/EIA-422" or even "TTL Differential".

# Reverse EngineeringPin Functions

You might encounter three different scale wiring configurations:

Four wires: +5V, 0V, A, B
Five wires: +5V, 0V, A, B, R (or Z)
Eight wires: +5V, 0V, A, B, R (or Z), A', B', R' (or Z')

The steps needed to reverse engineer the pin functions will differ slightly, depending on the type of your scales. Fortunately, all common Chinese DRO scales use variations of the same circuit based on the common LM339 quad comparator. The better single-ended scales use a slightly more sophisticated version that includes a dozen or so of extra components; the sub $100 scales use a very basic circuit that includes a through-hole version of the comparator, two potentiometers, and one or two capacitors. Finally, the differential scales use two comparator chips.

# RequiredTools

To identify the pin functions, you will need a basic multimeter that can test voltage and resistance or continuity. Additionally, you will need a way to provide a 5V power supply. If you intend to use a TouchDRO Adapter, it can be used to provide clean 5V supply. Otherwise, you can improvise something by using an old phone charger and cutting off the USB plug.

## Step 1 - Gain Access to The Circuit

First, take apart the DB9 connector to gain access to the wires. Chances are, individual contacts might be covered with small pieces of shrink tubing; in most cases, you can just slide them off..

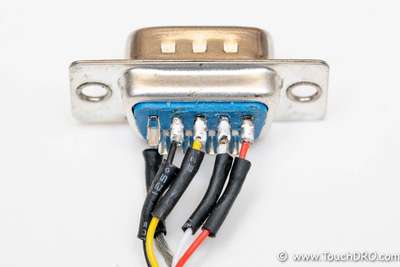
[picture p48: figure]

Shrink tubing pulled back to expose the contacts

Second, take the small metal cover off the scale's reading head. It's held in place by two small Phillips screws. The cover will likely be somewhat stuck to the case, so you will need to use a small flat screwdriver to pry it off. Inside, you will see a circuit that looks similar to the pictures below.

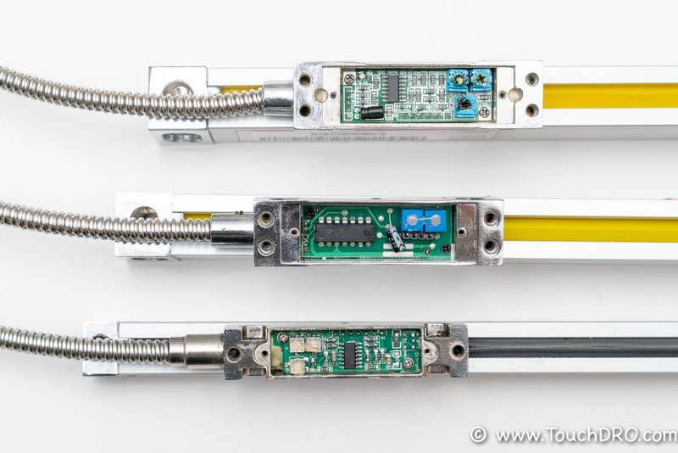
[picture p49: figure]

Easson, Jino, and Ditron scales's electronics are based on LM339 IC

The relatively large black component is the LM339 comparator IC. It can come in two flavors (packages) - the larger "through-hole" and smaller "surface-mount". The pinout is identical, so the difference is only how you find the first pin. On the through-hole package, there is a small tab on the one of the shorter edges; on the surface-mount package, there might be a small dot in one of the corners, or one of the long edges might have a pronounced bevel. All three indicate the position of the first pin:

The dot is next to pin #1
With the tab pointing up, the first pin will be in the upper left corner
With the bevel side on the left, pin #1 will be in the upper left corner

Note: Going forward, we will position the IC so the pin #1 is in the upper left corner.

## Step 2 - Identify The Power Supply Pins

This step will be identical for all three types of DRO scales:

1. Switch your multimeter to the "Resistance" mode or, if available, "Continuity" (A.K.A. "Beep") mode.
2. Counting from the top of the IC on the left side, find the third pin. This is a positive supply for the comparator, also called "Vcc"..

3. Place one of the multimeter leads on that pin and probe continuity between it and the wires connected to the DB9 connector.
4. You will notice that one wire will get you a reading on the order of 10-20Ohms, while the others will be on the order of KiloOhms. Mark this wire as +5V.
5. The pin that is directly opposite the Vcc is the comparator's Ground pin (third from the top on the right side). Repeat the steps above and mark the wire with the lowest resistance as "Ground"

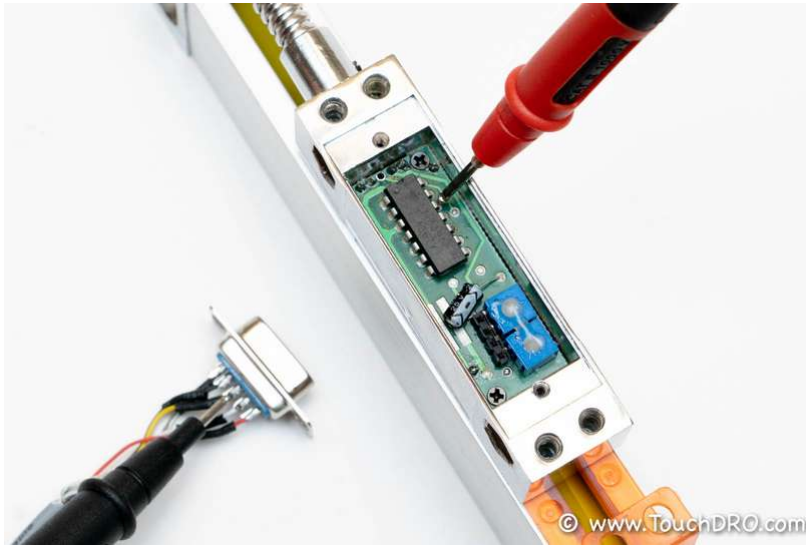
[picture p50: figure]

Third pin on the right is connected to the ground

If your scales have only four wires (plus braided shield), you are done. The other two wires are lines A and B. For most DRO units, it doesn't matter which is which since you can reverse the direction of reading in the settings.

## Step 3 - Power Up The Scale

To identify the pulse lines, you will need to power up the scale. If you're using the TouchDRO adapter, you can start assembling one of the provided DB9 pigtail cables such that the red lead is connected to the pin you marked +5V and the black lead to the pin you marked ground. Once done, plug the molex connector into one of the axis inputs of the TouchDRO adapter and power up the board.

For more information on how to put together and connect the pigtail connector assembly please refer to the instructions page for your version of the TouchDRO Scale Adapter.

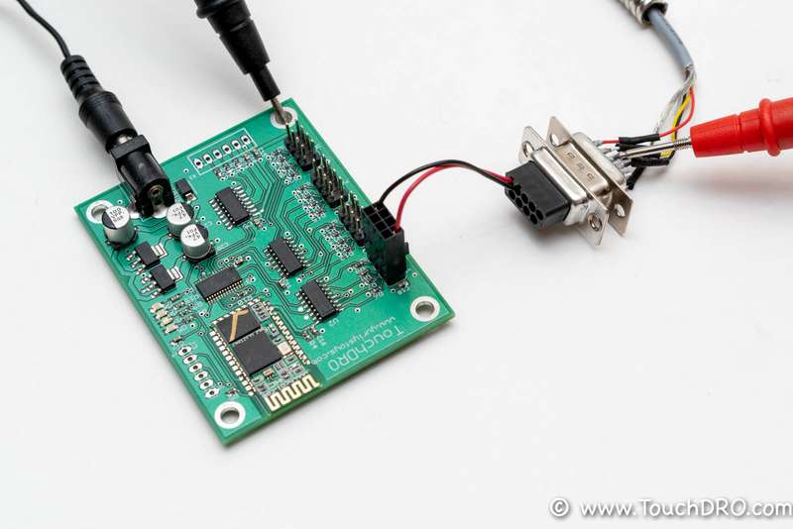
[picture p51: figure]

TouchDRO can be used to power the scale

From this point the steps will differ, depending on whether or not you have differential scales.

## Step 4 - Identify the Pulse Lines

## Single-Ended Scales

Let's start with the simpler case or single-ended scales. At this point, you will have three wires that are not marked. As you might recall from the above, two will be lines A and B, and one will be the reference signal. There are two possibilities here:

Most commonly, the reference line will output a square wave with a period that is several times larger than the other two lines.
Very rarely, the line will output short pulses at relatively long distances (tens of millimeters apart).
1. Switch your multimeter to "Voltage" mode.
2. Connect the black (negative) lead to the scales "Ground" line. If using a TouchDRO adapter, you can insert the lead into one of the PCB mounting holes since they are connected to the ground.
3. Connect the red (positive) lead to one of the unidentified lines. You should see voltage reading close to 5V or 0V, depending on the position of the reading head.
4. Going forward we will refer to a value that is close to 5V as "high" and a value that is close to 0V as "low".

5. Carefully tap the reading head to move it lenght-vise until the voltage changes from low to high or vice versa.
6. Note how much you had to move the head.
7. Repeat steps 4 and 6 for the other two lines.

You will notice that out of the three lines, one needed to be moved much farther than the other two for the voltage to change. This is the "reference" line; the other two lines are A and B.

## Differential Scales

Steps 1-5 above apply to the differential scales, but since there are twice as many lines, you will need to do a bit more work.

1. Repeat steps 4 and 5 above for the rest of the lines
2. You will notice that two of them needed to be moved farther for the voltage to change; mark them as "Reference"

Now you will need to identify A/A' and B/B' pairs. For this, you will need to move the scale several times and measure the voltage. It will be useful to make a table like the example below:

Wire Color | Test 1 | Test 2 | Test 3 | Test 4 | Test 5
Yellow | High | High | Low | Low | Low
Green | Low | High | High | Low | High
Blue | Low | Low | High | High | High
Brown | High | Low | Low | High | Low

You will notice that pairs Yellow/Blue and Geen/Brown never have the same reading. I.e. when Yellow is high, Blue is low, and vice versa. These are in fact A/A' and B/B' pairs. At this point, you don't know which of the lines is primary and which is complementary, but fortunately, this is not important in most cases. Reversing the primary and complementary lines reverses the direction of reading, but that can be changed in the DRO settings.

| | Terms and Conditions (https://www.touchdro.com/terms-and-conditions.html) | | Contact Us (https://www.touchdro.com/contact-us.html)
Privacy Policy (https://www.touchdro.com/app-privacy-policy.html)
Copyright 2012-2023 Yuriy's Toys, LLC.

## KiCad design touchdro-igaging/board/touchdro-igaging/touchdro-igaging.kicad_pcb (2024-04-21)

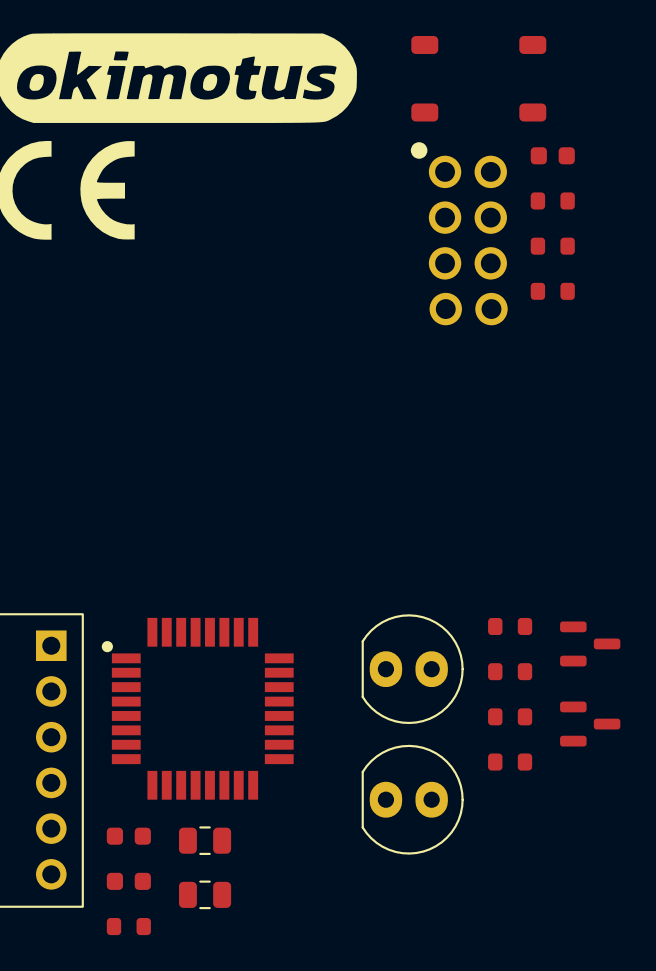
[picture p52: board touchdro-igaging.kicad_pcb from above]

Board: 4 copper layers, 27 parts (0 on the bottom side), 12 nets, no tracks yet.

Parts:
C5, C7: 0805_10uF; C_0805
C6, C8, C35: 0603_100nF; C_0603
G1: CE 8mm; ce-8mm
G2: Okimotus Logo; okimotus-logo-20mm
H7, H8, H9, H10: Screw-3.2mm; ScrewHole-3.2mm
ISP1: AVR_ISP_8pin; AVR_ISP_8pin_VCC
LED1: LED_TH_5mm_Green; LED_D5.0mm_Green
LED2: LED_TH_5mm_Red; LED_D5.0mm_Red
Q2, Q3: AO3400A
R3, R48, R49: 0603_100; R_0603
R47: 0603_4K7; R_0603
R56, R58: 0603_470; R_0603
R57, R59: 0603_10K; R_0603
SW1: TS-1187A-B-A-B
U1: ATMEGA328PB-AU
U2: HC05

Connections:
/AVCC: C7.1, C8.1, R3.2, U1.18 (AVCC)
/LED_{1}: Q2.G, R57.1
/LED_{2}: Q3.G, R59.1
/~RESET: C35.1, R47.2, R48.1, R49.2, U1.29 (nRESET__[22]__PC6)
GND: C5.2, C6.2, C7.2, C8.2, C35.2, ISP1.GND, Q2.S, Q3.S, R57.2, R59.2, SW1.1, U1.5 (GND), U1.21 (GND)
unnamed: ISP1.RST, R48.2
unnamed: LED1.C, R56.2
unnamed: LED2.C, R58.2
unnamed: Q2.D, R56.1
unnamed: Q3.D, R58.1
unnamed: R49.1, SW1.2
VCC: C5.1, C6.1, ISP1.VCC, LED1.A, LED2.A, R3.1, R47.1, U1.4 (VCC)

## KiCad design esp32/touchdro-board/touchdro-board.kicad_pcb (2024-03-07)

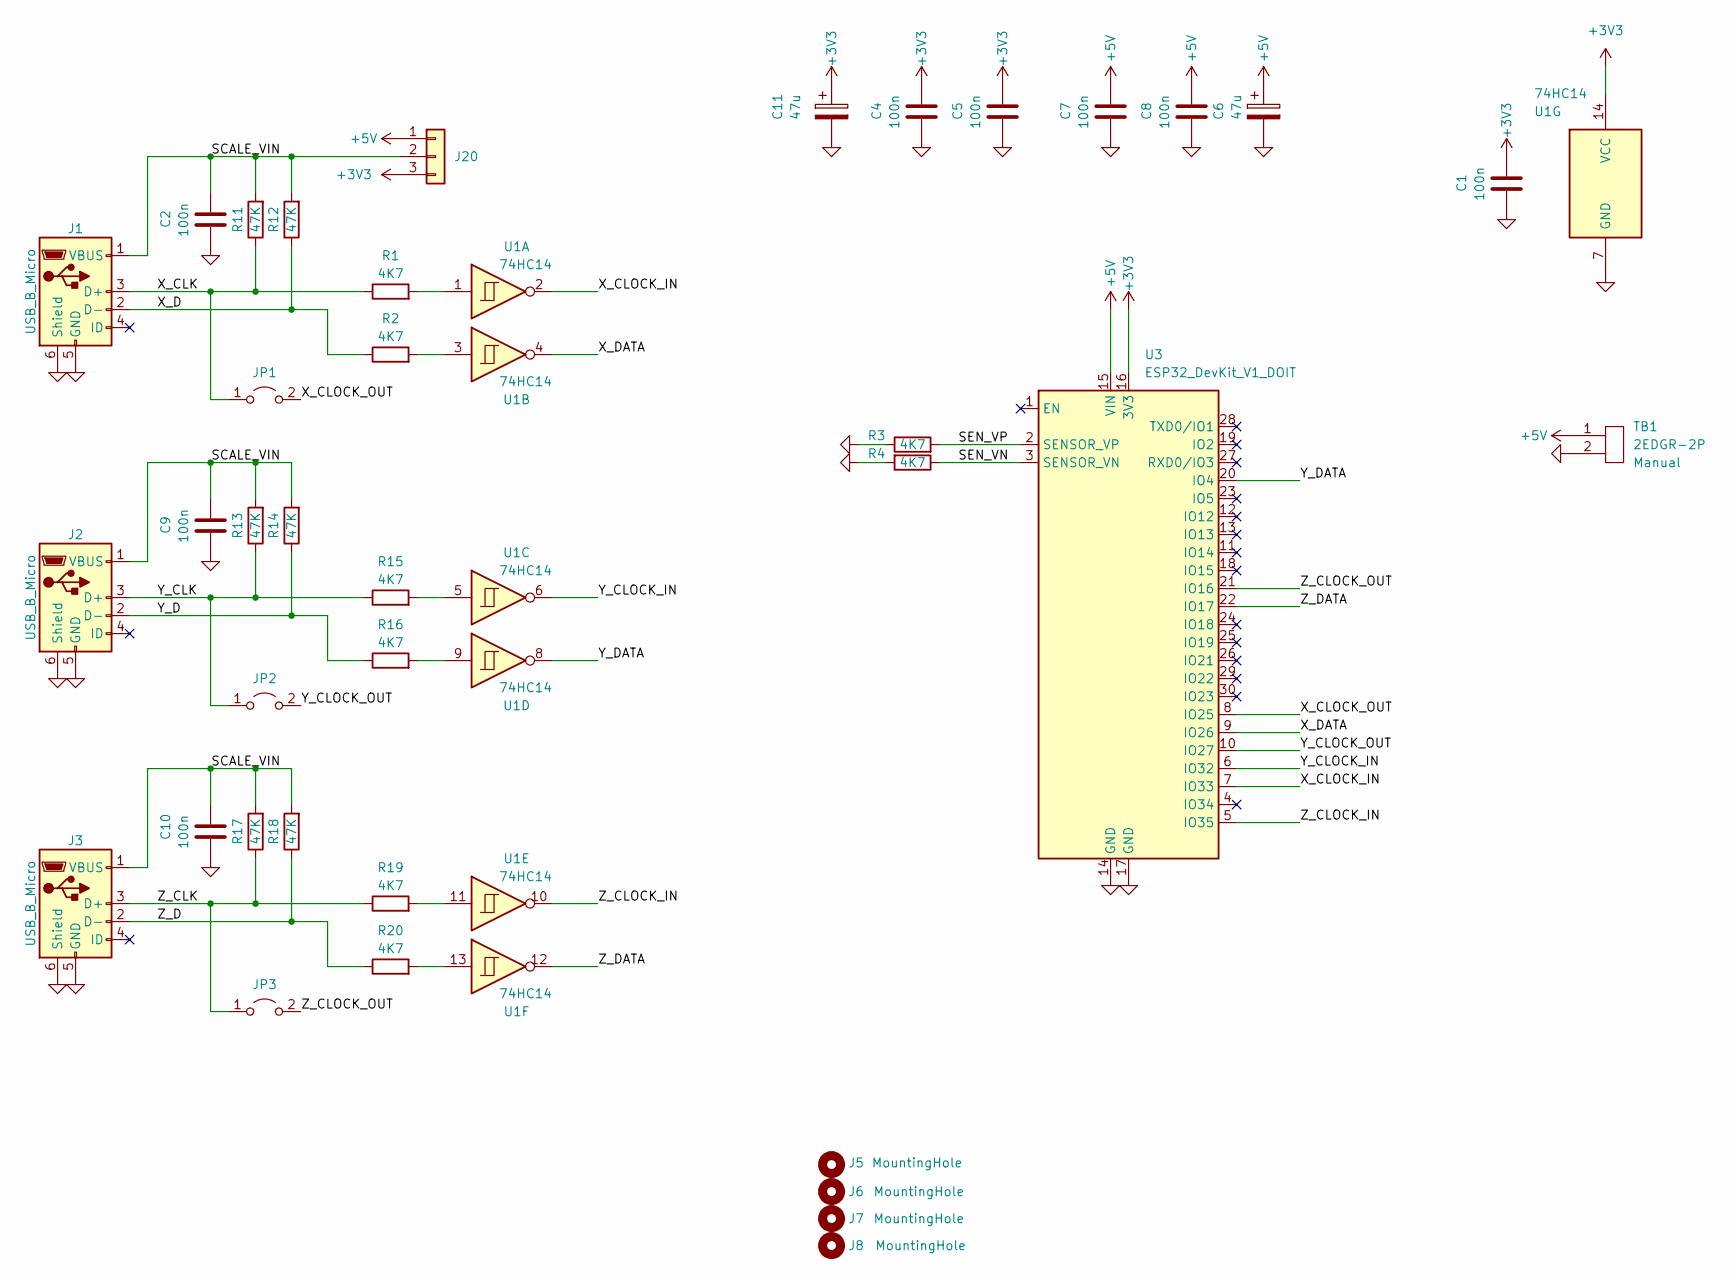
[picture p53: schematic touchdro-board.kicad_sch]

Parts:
C1, C2, C4, C5, C7, C8, C9, C10: 100n; C_Rect_L7.2mm_W3.0mm_P5.00mm_FKS2_FKP2_MKS2_MKP2; LCSC C3034534
C6, C11: 47u; CP_Radial_D8.0mm_P3.50mm; LCSC 03EC0571
J1, J2, J3: USB_B_Micro; MicroUSB
J5, J6, J7, J8: MountingHole; MountingHole_3.5mm
J20: Conn_01x03; PinHeader_1x03_P2.54mm_Vertical
JP1, JP2, JP3: Jumper_2_Open; PinHeader_1x02_P2.54mm_Vertical
R1, R2, R3, R4, R15, R16, R19, R20: 4K7; R_Axial_DIN0207_L6.3mm_D2.5mm_P7.62mm_Horizontal; LCSC C119339
R11, R12, R13, R14, R17, R18: 47K; R_Axial_DIN0207_L6.3mm_D2.5mm_P7.62mm_Horizontal; LCSC C410613
TB1: 2EDGR-2P
U1: 74HC14; DIP-14_W7.62mm; LCSC C2907
U3: ESP32_DevKit_V1_DOIT; esp32_devkit_v1_doit

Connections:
+3V3: C1.1, C4.1, C5.1, C11.1, J20.3, U1.14 (VCC), U3.16 (3V3)
+5V: C6.1, C7.1, C8.1, J20.1, TB1.1, U3.15 (VIN)
/SCALE_VIN: C2.1, C9.1, C10.1, J1.1 (VBUS), J2.1 (VBUS), J3.1 (VBUS), J20.2, R11.2, R12.2, R13.2, R14.2, R17.2, R18.2
/SEN_VN: R4.1, U3.3 (SENSOR_VN)
/SEN_VP: R3.2, U3.2 (SENSOR_VP)
/X_CLK: J1.3 (D+), JP1.1 (A), R1.1, R11.1
/X_CLOCK_IN: U1.2, U3.7 (IO33)
/X_CLOCK_OUT: JP1.2 (B), U3.8 (IO25)
/X_D: J1.2 (D-), R2.1, R12.1
/X_DATA: U1.4, U3.9 (IO26)
/Y_CLK: J2.3 (D+), JP2.1 (A), R13.1, R15.1
/Y_CLOCK_IN: U1.6, U3.6 (IO32)
/Y_CLOCK_OUT: JP2.2 (B), U3.10 (IO27)
/Y_D: J2.2 (D-), R14.1, R16.1
/Y_DATA: U1.8, U3.20 (IO4)
/Z_CLK: J3.3 (D+), JP3.1 (A), R17.1, R19.1
/Z_CLOCK_IN: U1.10, U3.5 (IO35)
/Z_CLOCK_OUT: JP3.2 (B), U3.21 (IO16)
/Z_D: J3.2 (D-), R18.1, R20.1
/Z_DATA: U1.12, U3.22 (IO17)
GND: C1.2, C2.2, C4.2, C5.2, C6.2, C7.2, C8.2, C9.2, C10.2, C11.2, J1.5 (GND), J1.6 (Shield), J2.5 (GND), J2.6 (Shield), J3.5 (GND), J3.6 (Shield), R3.1, R4.2, TB1.2, U1.7 (GND), U3.14 (GND), U3.17 (GND)
unnamed: R1.2, U1.1
unnamed: R2.2, U1.3
unnamed: R15.2, U1.5
unnamed: R16.2, U1.9
unnamed: R19.2, U1.11
unnamed: R20.2, U1.13

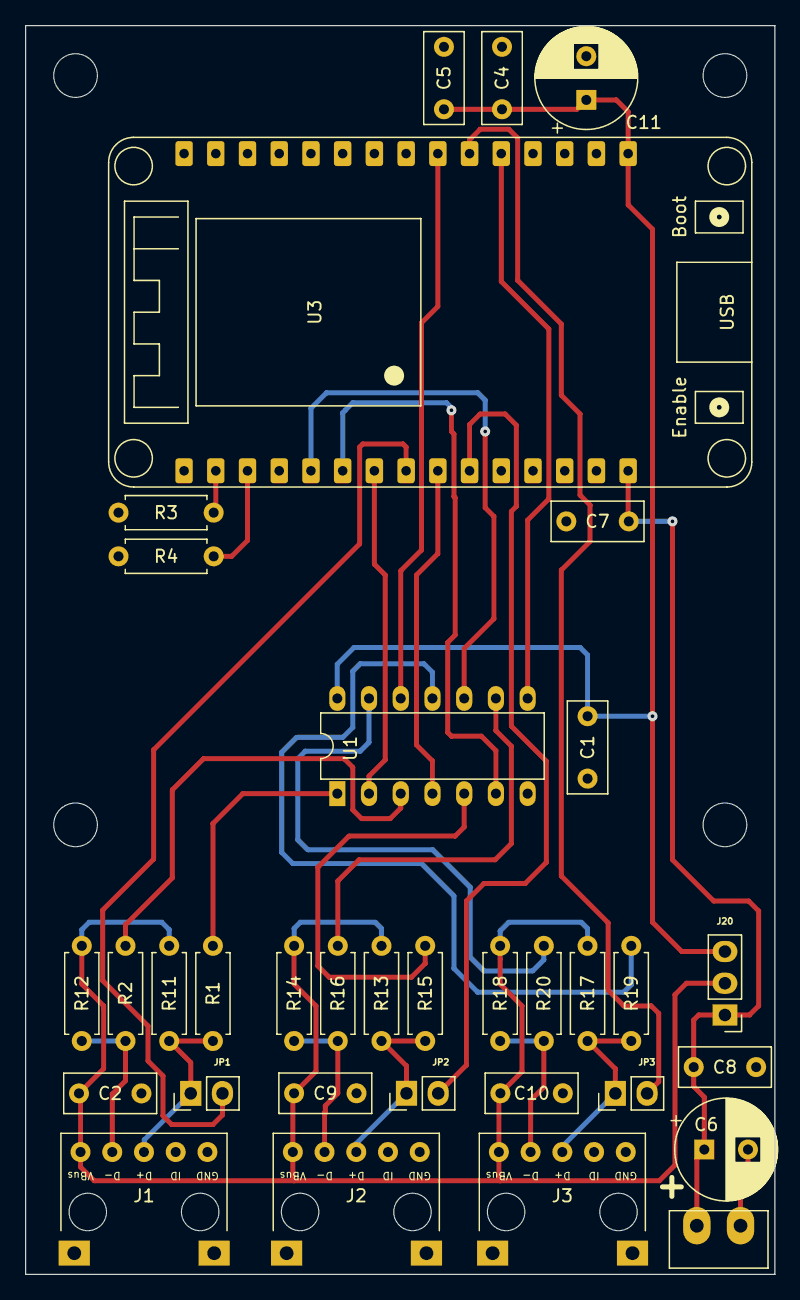
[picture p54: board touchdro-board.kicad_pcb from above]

Board: 2 copper layers, 60.0 x 100.0 mm, 38 parts (0 on the bottom side), 27 nets.

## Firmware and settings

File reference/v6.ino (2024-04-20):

/*
 NOTE: This program supports pulse sensor to measure rpm and switch type touch probe .  For quadrature encoder scales use LS7366R-based shield.
 If at least one quadrature scale is used do not conect other devices to SPI dedicated pins as LS7366R uses SPI for communication
 Read your Arduino board documentation for SPI pins as on some boards they are shared with "normal" I/O pins (on Arduino UNO it is 11, 12 and 13).
 
 Configuration parameters:
	SCALE_<n>_ENABLED
		Defines if DRO functionality on axis <n> should be supported.  
		If supported DRO scale should be connected to I/O pin defined in constant "<n>DataPin" and 
		DRO data is sent to serial port with corresponding axis prefix (X, Y, Z or W)
		Clock pin is common for all iGaging scales should be connected to I/O pin defined in constant "clockPin" 
		Possible values:
			0 = DRO functionality on axis <n> is not supported
			1 = DRO functionality on axis <n> is supported
		Default value = 1

	SCALE_<n>_TYPE
		Defines the type of scale used on axis <n>.  
		Two types of scales are supported: iGaging/AccuRemote Digital Scales and  quadrature encoder scales (common glass or magnetic)
		Note: If at least on scale is type 1 do not connect any other devices to SPI pins as it will interfere with communication with LS7366R.
		Possible values:
			0 = iGaging/AccuRemote Digital Scales with 21bit protocol
			1 = Quadrature Encoder scales through LS7366R-type shield (32-bit quadrature counter with serial interface).
		Default value = 0

	SCALE_CLK_PIN
		Defines the I/O pin where clock signal for all iGaging DRO scales is connected.  Used only if at least one scale is type 0.
		Possible values:
			integer number between 2 and 13
		Default value = 2

	SCALE_<n>_PIN
		Defines the I/O pin where DRO data signal for selected scale is connected
		Note: For quadrature scale this pin is connected to SPI SS pin in corresponding LS7366R.
		Possible values:
			integer number between 2 and 13
		Default values = 3, 4, 5, 6 (for corresponding axis X, Y, Z and W)

	SCALE_<n>_AVERAGE_ENABLED
		Defines if DRO reading should be averaged using weighted average calculation with automating smoothing factor.   
		If average is enabled the reading is much more stable without "jumping" and "flickering" when the scale "can't decide" on the value.  
		Note: This value is not used when corresponding SCALE_<n>_ENABLED is 0 
		Possible values:
			0 = exact measured from the scale is sent
			1 = scale reading averaged using weighted average calculation with automatic smoothing factor
		Default value = 1

	AXIS_AVERAGE_COUNT
		Defines the number of last DRO readings that will be used to calculate weighted average for DRO.
		For machines with power feed on any axis change this value to lower number i.e. 8 or 16.
		Possible values:
			integer number between 4 and 32 
		Recommended values:
			16 for machines with power feed 
			32 for all manual machines
		Default value = 24

	TACH_ENABLED
		Defines if tach sensor functionality should be supported.  
		If supported tach sensor should be connected to I/O pin defined in constant INPUT_TACH_PIN and 
		rpm value is sent to serial port with axis prefix "T" 
		Possible values:
			0 = tach sensor functionality is not supported
			1 = tach sensor functionality is supported
		Default value = 1

	INPUT_TACH_PIN
		Defines the I/O pin where tach sensor signal is connected
		Possible values:
			integer number between 2 and 13
		Default value = 7

	TACH_PRESCALE
		Defines how many tach pulses per one revolution the sensor sends.  
		For example if tach sensor uses two magnets on the shaft the sensor will generate two pulses per revolution.
		This can be used to get better resolution and faster response time for very low rpm
		Note: This value is not used when TACH_RAW_DATA_FORMAT is enabled 
		Possible values:
			any integer number greater than 0
		Default value = 1

	TACH_AVERAGE_COUNT
		Defines the number of last tach readings that will be used to calculate average tach rpm.
		If you want to send measured rpm instead of average rpm set this value to 1.
		Note: This value is not used when TACH_RAW_DATA_FORMAT is enabled.
		      It is recommended to set this value 2 times or more of TACH_PRESCALE value.
		      For example: if TACH_PRESCALE = 4, set TACH_AVERAGE_COUNT = 8
		Possible values:
			1 = exact measured tach reading is sent
			any integer number greater than 1 - average tach reading is sent 
		Default value = 6

	TACH_ROUND
		Defines how tach reading should be rounded.   
		If rounding is enabled the reading can be rounded either by 1% of current rpm or to the fixed "round" number with predefined RPM thresholds ("smart rounding"). 
		For example with 1% rounding if measured rpm is between 980rpm and  1020 rpm the display will show numbers rounded to 9 and 10 (i.e. 981, 990, 999, 1000, 1010, 1020 etc.). 
		With "smart rounding" the measured rpm is rounded to the nearest 1, 2, 5, 10, 20, 50 and 100 depends on measured RPM (change at predefined thresholds).
		For example with "smart rounding" all measured rpm is between 500pm and  2000 rpm the display will show numbers rounded to the nearest 5 (i.e. 980, 985, 990, 995, 1000, 1005  etc.). 
		Note: This value is not used when TACH_RAW_DATA_FORMAT is enabled 
		Possible values:
			0 = exact measured tach reading is sent
			1 = tach reading is rounded to the nearest 1% of measured rpm (1% rounding)
			2 = tach reading is rounded to the nearest "round" number with fixed thresholds ("smart rounding")
		Default value = 2

	TACH_RAW_DATA_FORMAT
		Defines the format of tach data sent to serial port.
		Note: when raw data format is used, then TACH_PRESCALE, TACH_AVERAGE_COUNT and TACH_ROUND are ignored 
		Possible values:
			0 = tach data is sent in single value format: T<rpm>;
			1 = tach data is sent in raw (two values) format: T<total_time>/<number_of_pulses>;
		Default value = 0

	MIN_RPM_DELAY
		Defines the delay (in milliseconds) in showing 0 when rotation stops.  If rpm is so low and time between tach pulse
		changes longer than this value, value zero rpm ("T0;") will be sent to the serial port.
		Note: this number will determine the slowest rpm that can be measured.  In order to measure smaller rpm I suggest 
		      to use a sensor with more than one "ticks per revolution" (for example hall sensor with two or more magnets).
		      The number of "ticks per revolution" should be set in tachometer setting in Android app.
		Possible values:
			any integer number greater than 0
		Default value = 1200 (the minimum rpm measured will be 50 rpm)

	OUTPUT_TACH_LED_ENABLED
		Defines if the tach LED feedback is supported.  
		If supported the tach feedback LED should be connected to I/O pin defined in constant OUTPUT_TACH_LED_PIN below 
		Possible values:
			0 = tach LED feedback functionality is not supported
			1 = tach LED feedback functionality is supported
		Default value = 1

	OUTPUT_TACH_LED_PIN
		Defines the I/O pin where the tach LED feedback is connected.  
		Tach LED feedback indicates the status of INPUT_TACH_PIN for debugging purposes
		Possible values:
			integer number between 2 and 13
		Default value = 9

	PROBE_ENABLED
		Defines if touch probe sensor functionality should be supported.  
		If supported touch probe should be connected to I/O pin defined in constant INPUT_PROBE_PIN.   
		Possible values:
			1 = touch probe functionality is supported
			0 = touch probe functionality is not supported
		Default value = 1

	INPUT_PROBE_PIN
		Defines the I/O pin where touch probe signal is connected
		Possible values:
			integer number between 2 and 13
		Default value = 8

	PROBE_INVERT
		Defines if the touch probe input pin signal needs to be inverted (enter the signal level when touch probe is not touching).
		Possible values:
			0 = touch probe input pin signal is LOW (logical Zero) when touch probe is in "normal open" status (not touching)
			1 = touch probe input pin signal is HIGH (logical One) when touch probe is in "normal open" status (not touching)
		Default value = 0

	OUTPUT_PROBE_LED_ENABLED
		Defines if the touch probe LED feedback is supported.  
		If supported the touch probe feedback LED should be connected to I/O pin defined in constant INPUT_PROBE_PIN below 
		Possible values:
			1 = touch probe LED feedback functionality is supported
			0 = touch probe LED feedback functionality is not supported
		Default value = 1

	OUTPUT_PROBE_LED_PIN
		Defines the I/O pin where the touch probe LED feedback is connected.  
		Touch probe LED feedback indicates the status of INPUT_PROBE_PIN for debugging purposes
		Possible values:
			integer number between 2 and 13
		Default value = 10

	UART_BAUD_RATE
		Defines the serial port baud rate.  Make sure it matches the Bluetooth module's baud rate.
		Recommended value:
			1200, 2400, 4800, 9600, 19200, 38400, 57600, 115200
		Default value = 9600

	UPDATE_FREQUENCY
		Defines the Frequency in Hz (number of timer per second) the scales are read and the data is sent to the application.
		Possible values:
			any integer number between 1 and 64 
		Default value = 24
		
	TACH_UPDATE_FREQUENCY
		Defines the max Frequency in Hz (number of timer per second) the tach output is sent to the application.
		Note: This value must be a divider of UPDATE_FREQUENCY that would result zero reminder.
		      For example for UPDATE_FREQUENCY = 24 valid TACH_UPDATE_FREQUENCY are: 1, 2, 3, 4, 6, 8, 12 and 24 
		Possible values:
			any integer number between 1 and UPDATE_FREQUENCY 
		Default value = 4

 */
 

// DRO config (if axis is not connected change in the corresponding constant value from "1" to "0")
#define SCALE_X_ENABLED 1
#define SCALE_Y_ENABLED 1
#define SCALE_Z_ENABLED 1
#define SCALE_W_ENABLED 1

// DRO config (if axis is connected to Quadrature Encoder scales through LS7366R-type shield change in the corresponding constant value from "0" to "1")
#define SCALE_X_TYPE 0
#define SCALE_Y_TYPE 0
#define SCALE_Z_TYPE 0
#define SCALE_W_TYPE 0

// I/O ports config (change pin numbers if DRO, Tach sensor or Tach LED feedback is connected to different ports)
#define SCALE_CLK_PIN 2

#define SCALE_X_PIN 3
#define SCALE_Y_PIN 4
#define SCALE_Z_PIN 5
#define SCALE_W_PIN 6

// DRO rounding On/Off (if not enabled change in the corresponding constant value from "1" to "0")
#define SCALE_X_AVERAGE_ENABLED 1
#define SCALE_Y_AVERAGE_ENABLED 1
#define SCALE_Z_AVERAGE_ENABLED 1
#define SCALE_W_AVERAGE_ENABLED 1

// DRO rounding sample size.  Change it to 16 for machines with power feed
#define AXIS_AVERAGE_COUNT 24

// Tach config (if Tach is not connected change in the corresponding constant value from "1" to "0")
#define TACH_ENABLED 1
#define INPUT_TACH_PIN 7

// Tach pre-scale value (number of tach sensor pulses per revolution)
#define  TACH_PRESCALE 1

// Number of tach measurements to average 
#define TACH_AVERAGE_COUNT 6

// This is rounding for tachometer display (set to 0 to disable or 1 for 1% rounding)
#define TACH_ROUND 2

// Tach data format
#define TACH_RAW_DATA_FORMAT 0			// single value format: T<rpm>;

// Tach RPM config
#define MIN_RPM_DELAY 1200				// 1.2 sec calculates to low range = 50 rpm.

// Tach LED feadback config
#define OUTPUT_TACH_LED_ENABLED 1
#define OUTPUT_TACH_LED_PIN 9


// Touch probe config (if Touch Probe is not connected change in the corresponding constant value from "1" to "0")
#define PROBE_ENABLED 1
#define INPUT_PROBE_PIN 8				// Pin 8 connected to Touch Probe

// Touch probe invert signal config
#define PROBE_INVERT 0					// Touch Probe signal inversion: Open = Input pin is Low; Closed = Input pin is High

// Touch probe LED feadback config
#define OUTPUT_PROBE_LED_ENABLED 1
#define OUTPUT_PROBE_LED_PIN 10			// When Quadrature Encoder scale are not used, on Arduino Uno you may change it to on-board LED pin 13.


// General Settings
#define UART_BAUD_RATE 9600				//  Set this so it matches the BT module's BAUD rate 
#define UPDATE_FREQUENCY 24				//  Frequency in Hz (number of timer per second the scales are read and the data is sent to the application)
#define TACH_UPDATE_FREQUENCY 4 		//  Max Frequency in Hz (number of timer per second) the tach output is sent to the application

//---END OF CONFIGURATION PARAMETERS ---


//---DO NOT CHANGE THE CODE BELOW UNLESS YOU KNOW WHAT YOU ARE DOING ---

/* iGaging Clock Settings (do not change) */
#define SCALE_CLK_PULSES 21				// iGaging and Accuremote scales use 21 bit format
#define SCALE_CLK_FREQUENCY 9000		// iGaging scales run at about 9-10KHz
#define SCALE_CLK_DUTY 20				// iGaging scales clock run at 20% PWM duty (22us = ON out of 111us cycle)

/* weighted average constants */ 
#define FILTER_SLOW_EMA AXIS_AVERAGE_COUNT	// Slow movement EMA
#define FILTER_FAST_EMA 2 					// Fast movement EMA


#if (SCALE_X_ENABLED > 0) || (SCALE_Y_ENABLED > 0) || (SCALE_Z_ENABLED > 0) || (SCALE_W_ENABLED > 0)
#define DRO_ENABLED 1
#else
#define DRO_ENABLED 0
#endif

#if (SCALE_X_ENABLED > 0 && SCALE_X_TYPE == 0) || (SCALE_Y_ENABLED > 0 && SCALE_Y_TYPE == 0) || (SCALE_Z_ENABLED > 0 && SCALE_Z_TYPE == 0) || (SCALE_W_ENABLED > 0 && SCALE_W_TYPE == 0)
#define DRO_TYPE0_ENABLED 1
#else
#define DRO_TYPE0_ENABLED 0
#endif

#if (SCALE_X_ENABLED > 0 && SCALE_X_TYPE == 1) || (SCALE_Y_ENABLED > 0 && SCALE_Y_TYPE == 1) || (SCALE_Z_ENABLED > 0 && SCALE_Z_TYPE == 1) || (SCALE_W_ENABLED > 0 && SCALE_W_TYPE == 1)
#define DRO_TYPE1_ENABLED 1
#else
#define DRO_TYPE1_ENABLED 0
#endif


#if (SCALE_X_AVERAGE_ENABLED > 0) || (SCALE_Y_AVERAGE_ENABLED > 0) || (SCALE_Z_AVERAGE_ENABLED > 0) || (SCALE_W_AVERAGE_ENABLED > 0)
#define SCALE_AVERAGE_ENABLED 1
#else
#define SCALE_AVERAGE_ENABLED 0
#endif

// Define registers and pins for scale ports
#if SCALE_CLK_PIN < 8 
#define CLK_PIN_BIT SCALE_CLK_PIN
#define SCALE_CLK_DDR DDRD
#define SCALE_CLK_OUTPUT_PORT PORTD
#else
#define CLK_PIN_BIT (SCALE_CLK_PIN - 8)
#define SCALE_CLK_DDR DDRB
#define SCALE_CLK_OUTPUT_PORT PORTB
#endif

#if SCALE_X_PIN < 8 
#define X_PIN_BIT SCALE_X_PIN
#define X_DDR DDRD
#define X_INPUT_PORT PIND
#define X_OUTPUT_PORT PORTD
#else
#define X_PIN_BIT (SCALE_X_PIN - 8)
#define X_DDR DDRB
#define X_INPUT_PORT PINB
#define X_OUTPUT_PORT PORTB
#endif
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
void loop()
{

	if (tickTimerFlag) {
		tickTimerFlag = false;

#if DRO_ENABLED > 0
#if DRO_TYPE1_ENABLED
		readEncoders();
#endif
		//print DRO positions to the serial port
#if SCALE_X_ENABLED > 0
#if SCALE_X_AVERAGE_ENABLED > 0
		scaleValueRounded(xReportedValue, axisLastReadX, axisLastReadPositionX, axisAMAValueX);
#endif
		Serial.print(F("X"));
		Serial.print((long)xReportedValue);
		Serial.print(F(";"));
#endif

#if SCALE_Y_ENABLED > 0
#if SCALE_Y_AVERAGE_ENABLED > 0
		scaleValueRounded(yReportedValue, axisLastReadY, axisLastReadPositionY, axisAMAValueY);
#endif
		Serial.print(F("Y"));
		Serial.print((long)yReportedValue);
		Serial.print(F(";"));
#endif

#if SCALE_Z_ENABLED > 0
#if SCALE_Z_AVERAGE_ENABLED > 0
		scaleValueRounded(zReportedValue, axisLastReadZ, axisLastReadPositionZ, axisAMAValueZ);
#endif
		Serial.print(F("Z"));
		Serial.print((long)zReportedValue);
		Serial.print(F(";"));
#endif

#if SCALE_W_ENABLED > 0
#if SCALE_W_AVERAGE_ENABLED > 0
		scaleValueRounded(wReportedValue, axisLastReadW, axisLastReadPositionW, axisAMAValueW);
#endif
		Serial.print(F("W"));
		Serial.print((long)wReportedValue);
		Serial.print(F(";"));
#endif

#endif


		// print Tach rpm to serial port
#if TACH_ENABLED > 0

		// Calculate tach data
		sendTachData = sendTachOutputData() || sendTachData;

		// Check tach reporting frequency
		tachUpdateFrequencyCounter++;
		if (tachUpdateFrequencyCounter >= tachUpdateFrequencyCounterLimit) {
			tachUpdateFrequencyCounter = 0;

			// Output tach data
			if (sendTachData) {
				sendTachData = false;

				Serial.print(F("T"));
#if TACH_RAW_DATA_FORMAT > 0
				Serial.print((unsigned long)tachReadoutMicrosec);
				Serial.print(F("/"));
				Serial.print((unsigned long)tachReadoutRotationCount);
#else
				Serial.print((unsigned long)tachReadoutRpm);
#endif
				Serial.print(F(";"));
			}
		}
#endif


		// print Touch Probe data to serial port
#if PROBE_ENABLED > 0
		// Calculate tach data
		probeReportedValue = readProbeOutputData();

		Serial.print(F("P"));
		Serial.print((unsigned int)probeReportedValue);
		Serial.print(F(";"));
#endif
	}
}


//initializes clock timer
void setupClkTimer()
{
	updateFrequencyCounter = 0;

	TCCR2A = 0;			// set entire TCCR2A register to 0
	TCCR2B = 0;			// same for TCCR2B

	// set compare match registers
#if DRO_TYPE0_ENABLED > 0
	OCR2A = scaleClockDutyLimit;			// default 44 = 22us
#else
	OCR2A = clockCounterLimit - 1;
#endif
	OCR2B = clockCounterLimit;			// default 222 = 111us

	// turn on Fast PWM mode
	TCCR2A |= _BV(WGM21) | _BV(WGM20);

	// Set CS21 bit for 8 prescaler //CS20 for no prescaler
	TCCR2B |= _BV(CS21);

	//initialize counter value to start at low pulse
#if DRO_TYPE0_ENABLED > 0
	TCNT2  = scaleClockDutyLimit + 1;
#else
	TCNT2  = 0;
#endif
	// enable timer compare interrupt A and B
	TIMSK2 |= _BV(OCIE2A) | _BV(OCIE2B);
	
}



/* Interrupt Service Routines */

// Timer 2 interrupt B ( Switches clock pin from low to high 21 times) at the end of clock counter limit
ISR(TIMER2_COMPB_vect) {

	// Set counter back to zero  
	TCNT2  = 0;  
#if DRO_TYPE0_ENABLED > 0
	// Only set the clock high if updateFrequencyCounter less than 21
	if (updateFrequencyCounter < SCALE_CLK_PULSES) {
		// Set clock pin high
		SCALE_CLK_OUTPUT_PORT |= _BV(CLK_PIN_BIT);
	}
#endif
}


// Timer 2 interrupt A ( Switches clock pin from high to low) at the end of clock PWM Duty counter limit
ISR(TIMER2_COMPA_vect) 
{
#if DRO_TYPE0_ENABLED > 0
	// Control the scale clock for only first 21 loops
	if (updateFrequencyCounter < SCALE_CLK_PULSES) {
	
		// Set clock low if high and then delay 2us
		if (SCALE_CLK_OUTPUT_PORT & _BV(CLK_PIN_BIT)) {
			SCALE_CLK_OUTPUT_PORT &= ~_BV(CLK_PIN_BIT);
			TCNT2  = scaleClockDutyLimit - scaleClockFirstReadDelay;
			return;
		}

		// read the pin state and shift it into the appropriate variables
		// Logic by Les Jones:
		//	If data pin is HIGH set bit 20th of the axis value to '1'.  Then shift axis value one bit to the right
		//  This is called 20 times (for bits received from 0 to 19)
		if (updateFrequencyCounter < SCALE_CLK_PULSES - 1) {
#if SCALE_X_ENABLED > 0 && SCALE_X_TYPE == 0
			if (X_INPUT_PORT & _BV(X_PIN_BIT))
				xValue |= ((long)0x00100000 );
			xValue >>= 1;
#endif

#if SCALE_Y_ENABLED > 0 && SCALE_Y_TYPE == 0
			if (Y_INPUT_PORT & _BV(Y_PIN_BIT))
				yValue |= ((long)0x00100000 );
			yValue >>= 1;
#endif

#if SCALE_Z_ENABLED > 0 && SCALE_Z_TYPE == 0
			if (Z_INPUT_PORT & _BV(Z_PIN_BIT))
				zValue |= ((long)0x00100000 );
			zValue >>= 1;
#endif

#if SCALE_W_ENABLED > 0 && SCALE_W_TYPE == 0
			if (W_INPUT_PORT & _BV(W_PIN_BIT))
				wValue |= ((long)0x00100000 );
			wValue >>= 1;
#endif


		} else if (updateFrequencyCounter == SCALE_CLK_PULSES - 1) {

			//If 21-st bit is 'HIGH' inverse the sign of the axis readout
#if SCALE_X_ENABLED > 0 && SCALE_X_TYPE == 0
			if (X_INPUT_PORT & _BV(X_PIN_BIT))
				xValue |= ((long)0xfff00000);
			xReportedValue = xValue;
			xValue = 0L;
#endif

#if SCALE_Y_ENABLED > 0 && SCALE_Y_TYPE == 0
			if (Y_INPUT_PORT & _BV(Y_PIN_BIT))
				yValue |= ((long)0xfff00000);
			yReportedValue = yValue;
			yValue = 0L;
#endif

#if SCALE_Z_ENABLED > 0 && SCALE_Z_TYPE == 0
			if (Z_INPUT_PORT & _BV(Z_PIN_BIT))
				zValue |= ((long)0xfff00000);
			zReportedValue = zValue;
			zValue = 0L;
#endif

#if SCALE_W_ENABLED > 0 && SCALE_W_TYPE == 0
			if (W_INPUT_PORT & _BV(W_PIN_BIT))
				wValue |= ((long)0xfff00000);
			wReportedValue = wValue;
			wValue = 0L;
#endif
			// Tell the main loop, that it's time to sent data
			tickTimerFlag = true;

		}
	}
#else
	if (updateFrequencyCounter == 0) {
		// Tell the main loop, that it's time to sent data
		tickTimerFlag = true;
	}
#endif
	
	updateFrequencyCounter++;
	// Start of next cycle 
	if ( updateFrequencyCounter >= updateFrequencyCounterLimit) {
		updateFrequencyCounter = 0;
	}

}


#if DRO_TYPE1_ENABLED
inline void readEncoders() {

#if SCALE_X_ENABLED > 0 && SCALE_X_TYPE == 1
	X_OUTPUT_PORT &= ~_BV(X_PIN_BIT);
	readEncoderValue();
	X_OUTPUT_PORT |= _BV(X_PIN_BIT);
    xReportedValue= ((long)encoderValue1<<24) + ((long)encoderValue2<<16) + ((long)encoderValue3<<8) + (long)encoderValue4;
#endif

#if SCALE_Y_ENABLED > 0 && SCALE_Y_TYPE == 1
	Y_OUTPUT_PORT &= ~_BV(Y_PIN_BIT);
	readEncoderValue();
	Y_OUTPUT_PORT |= _BV(Y_PIN_BIT);
    yReportedValue= ((long)encoderValue1<<24) + ((long)encoderValue2<<16) + ((long)encoderValue3<<8) + (long)encoderValue4;
#endif

#if SCALE_Z_ENABLED > 0 && SCALE_Z_TYPE == 1
	Z_OUTPUT_PORT &= ~_BV(Z_PIN_BIT);
	readEncoderValue();
	Z_OUTPUT_PORT |= _BV(Z_PIN_BIT);
    zReportedValue= ((long)encoderValue1<<24) + ((long)encoderValue2<<16) + ((long)encoderValue3<<8) + (long)encoderValue4;
#endif

#if SCALE_W_ENABLED > 0 && SCALE_W_TYPE == 1
	W_OUTPUT_PORT &= ~_BV(W_PIN_BIT);
	readEncoderValue();
	W_OUTPUT_PORT |= _BV(W_PIN_BIT);
    wReportedValue= ((long)encoderValue1<<24) + ((long)encoderValue2<<16) + ((long)encoderValue3<<8) + (long)encoderValue4;
#endif
}

inline void readEncoderValue() {
	SPI.transfer(0x60); // Request count
	encoderValue1 = SPI.transfer(0x00); // Read highest order byte
	encoderValue2 = SPI.transfer(0x00);
	encoderValue3 = SPI.transfer(0x00);
	encoderValue4 = SPI.transfer(0x00); // Read lowest order byte
}

#endif


#if DRO_ENABLED > 0
#if SCALE_AVERAGE_ENABLED > 0
inline void	initializeAxisAverage(volatile long axisLastRead[], volatile int &axisLastReadPosition, volatile long &axisAMAValue) {
	
	for (axisLastReadPosition = 0; axisLastReadPosition < (int) AXIS_AVERAGE_COUNT; axisLastReadPosition++) {
		axisLastRead[axisLastReadPosition] = 0;
	}
	axisLastReadPosition = 0;
	axisAMAValue = 0;

}
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

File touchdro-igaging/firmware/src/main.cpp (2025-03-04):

#include <Arduino.h>

#define cbi(sfr, bit)         (_SFR_BYTE(sfr) &= ~_BV(bit))
#define sbi(sfr, bit)         (_SFR_BYTE(sfr) |= _BV(bit))

#define CLK_PIN_BIT           2
#define SCALE_CLK_DDR         DDRD
#define SCALE_CLK_OUTPUT_PORT PORTD

#define X_PIN_BIT             3
#define X_DDR                 DDRD
#define X_INPUT_PORT          PIND

#define UART_BAUD_RATE        9600

//  Frequency in Hz (number of timer per second the scales are read and the data is sent to the application)
#define UPDATE_FREQUENCY      24

// iGaging and Accuremote scales use 21 bit format
#define SCALE_CLK_PULSES      21

// iGaging scales run at about 9-10KHz
#define SCALE_CLK_FREQUENCY   9000

// iGaging scales clock run at 20% PWM duty (22us = ON out of 111us cycle)
#define SCALE_CLK_DUTY        20

int const updateFrequencyCounterLimit = (int) (((uint64_t) SCALE_CLK_FREQUENCY) / ((uint64_t) UPDATE_FREQUENCY));
int const clockCounterLimit           = (int) (((uint64_t) (F_CPU / 8)) / (uint64_t) SCALE_CLK_FREQUENCY) - 10;
int const scaleClockDutyLimit         = (int) (((uint64_t) (F_CPU / 800)) * ((uint64_t) SCALE_CLK_DUTY) / (uint64_t) SCALE_CLK_FREQUENCY);
int const scaleClockFirstReadDelay    = (int) ((uint64_t) F_CPU / 4000000);

// variables that will store the DRO readout
volatile bool tickTimerFlag;
volatile int  updateFrequencyCounter;

// Axis count

volatile long xValue;
volatile long xReportedValue;

void setupClkTimer() {
    updateFrequencyCounter = 0;

    TCCR2A                 = 0;
    TCCR2B                 = 0;
    OCR2A                  = scaleClockDutyLimit;  // default 44 = 22us
    OCR2B                  = clockCounterLimit;    // default 222 = 111us

    // turn on Fast PWM mode
    TCCR2A |= (1 << WGM21) | (1 << WGM20);

    // Set CS21 bit for 8 prescaler // CS20 for no prescaler
    TCCR2B |= (1 << CS21);

    // initialize counter value to start at low pulse
    TCNT2 = scaleClockDutyLimit + 1;

    // enable timer compare interrupt A and B
    TIMSK2 |= (1 << OCIE2A) | (1 << OCIE2B);
}

// Timer 2 interrupt B (Switches clock pin from low to high 21 times) at the end of clock counter limit
ISR(TIMER2_COMPB_vect) {
    TCNT2 = 0;

    // Only set the clock high if updateFrequencyCounter less than 21
    if (updateFrequencyCounter < SCALE_CLK_PULSES) {
        // Set clock pin high
        SCALE_CLK_OUTPUT_PORT |= (1 << CLK_PIN_BIT);
    }
}

// Timer 2 interrupt A ( Switches clock pin from high to low) at the end of clock PWM Duty counter limit
ISR(TIMER2_COMPA_vect) {

    // Control the scale clock for only first 21 loops
    if (updateFrequencyCounter < SCALE_CLK_PULSES) {

        // Set clock low if high and then delay 2us
        if (SCALE_CLK_OUTPUT_PORT & (1 << CLK_PIN_BIT)) {
            SCALE_CLK_OUTPUT_PORT &= ~(1 << CLK_PIN_BIT);
            TCNT2 = scaleClockDutyLimit - scaleClockFirstReadDelay;
            return;
        }

        // read the pin state and shift it into the appropriate variables
        // Logic by Les Jones:
        //	If data pin is HIGH set bit 20th of the axis value to '1'.  Then shift axis value one bit to the right
        //  This is called 20 times (for bits received from 0 to 19)
        if (updateFrequencyCounter < SCALE_CLK_PULSES - 1) {

            if (X_INPUT_PORT & (1 << X_PIN_BIT)) {
                xValue |= ((long) 0x00100000);
            }
            xValue >>= 1;

        } else if (updateFrequencyCounter == SCALE_CLK_PULSES - 1) {

            // If 21-st bit is 'HIGH' inverse the sign of the axis readout

            if (X_INPUT_PORT & (1 << X_PIN_BIT))
                xValue |= ((long) 0xfff00000);
            xReportedValue = xValue;
            xValue         = 0L;

            // Tell the main loop, that it's time to sent data
            tickTimerFlag  = true;
        }
    }

    updateFrequencyCounter++;
    // Start of next cycle
    if (updateFrequencyCounter >= updateFrequencyCounterLimit) {
        updateFrequencyCounter = 0;
    }
}

void setup() {

    cli();

    tickTimerFlag          = false;
    updateFrequencyCounter = 0;

    // clock pin should be set as output
    SCALE_CLK_DDR |= (1 << CLK_PIN_BIT);
    // set the clock pin to low

    SCALE_CLK_OUTPUT_PORT &= ~(1 << CLK_PIN_BIT);

    X_DDR &= ~(1 << X_PIN_BIT);
    xValue         = 0L;
    xReportedValue = 0L;

    setupClkTimer();

    Serial.begin(UART_BAUD_RATE);
    sei();
}

int main() {
    setup();
    while (true) {
        if (tickTimerFlag) {
            tickTimerFlag = false;

            Serial.print(F("X"));
            Serial.print((long) xReportedValue);
            Serial.print(F(";"));
        }
    }
}
